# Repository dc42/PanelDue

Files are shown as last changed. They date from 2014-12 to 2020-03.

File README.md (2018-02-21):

PanelDue
========

This is the OLD source code for firmware versions 1.15x and earlier to run the PanelDue 3D printer user interface board. Source code for firmware versions 1.16 and later is in repository PanelDueFirmware, see https://github.com/dc42/PanelDueFirmware.

Build instructions: load file PanelDue.cppproj into Atmel Studio 7.0. For those wishing to build it under operating systems other than Windows, it should not be difficult to port it to Eclipse. The only libraries needed that are not included in this repository are the GCC toolchain libraries for the SAM3S.

Static analysis: parts of the firmware are formally verified using Escher C++ Verifier, hence the design-by-contract and other annotations. File ecv.h defines macros that make these annotations invisible to compilers.

Firmware upload instructions: see http://miscsolutions.wordpress.com/paneldue/

Licence and copyright
=====================

Copyright (c) 2015 Escher Technologies Limited. Licensed under the Creative Commons Attribution-NonCommercial 4.0 license. See https://creativecommons.org/licenses/by-nc/4.0/legalcode for a copy. Some parts of the firmware (c) Henning Karlsen. Some parts of the firmware (c) Atmel Inc.

Submitting pull requests
========================

I will only consider pull requests that meet the following standards:
- the code must compile warning-free, with very few exceptions
- existing design-by-contract annotations must be preserved, and contracts should be added for any new functions. Please asked for a copy of eCv++ Free Edition if you plan on making substantial changes.
- the coding style must be adhered to

Acknowledgements
================

Henning Karlsen - for the original versions of the TFT display driver, see http://www.henningkarlsen.com/electronics/
Atmel - for the Atmel Software Framework, which made programming the ATSAM3S a lot easier
MikroElectronika - for providing GLCD Font Creator, see http://www.mikroe.com/glcd-font-creator/
Andy (kwikius) - for writing a program to compress fonts generated by GLCD Font Creator

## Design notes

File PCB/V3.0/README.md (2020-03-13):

This is the schematic for the version 3.0 standalone PanelDue controller board. The PaneDue 5i with integrated display uses the same circuitry for the part that interfaces to the Duet, with the following changes:
1. A different 3.3V regulator chip is used
2. Connector X4 has a different pinout. Numbering the pins from the left (with the adjacent X4 legend), the pin connections are:
* Pin 1: PB6 (intended for rotary encoder push button)
* Pin 2: PA2 (intended for rotary encoder A pin)
* Pin 3: PA3 (intended for rotary encoder B pin)
* Pin 4: +3.3V
* Pin 5: Ground (rotary encoder common pin)

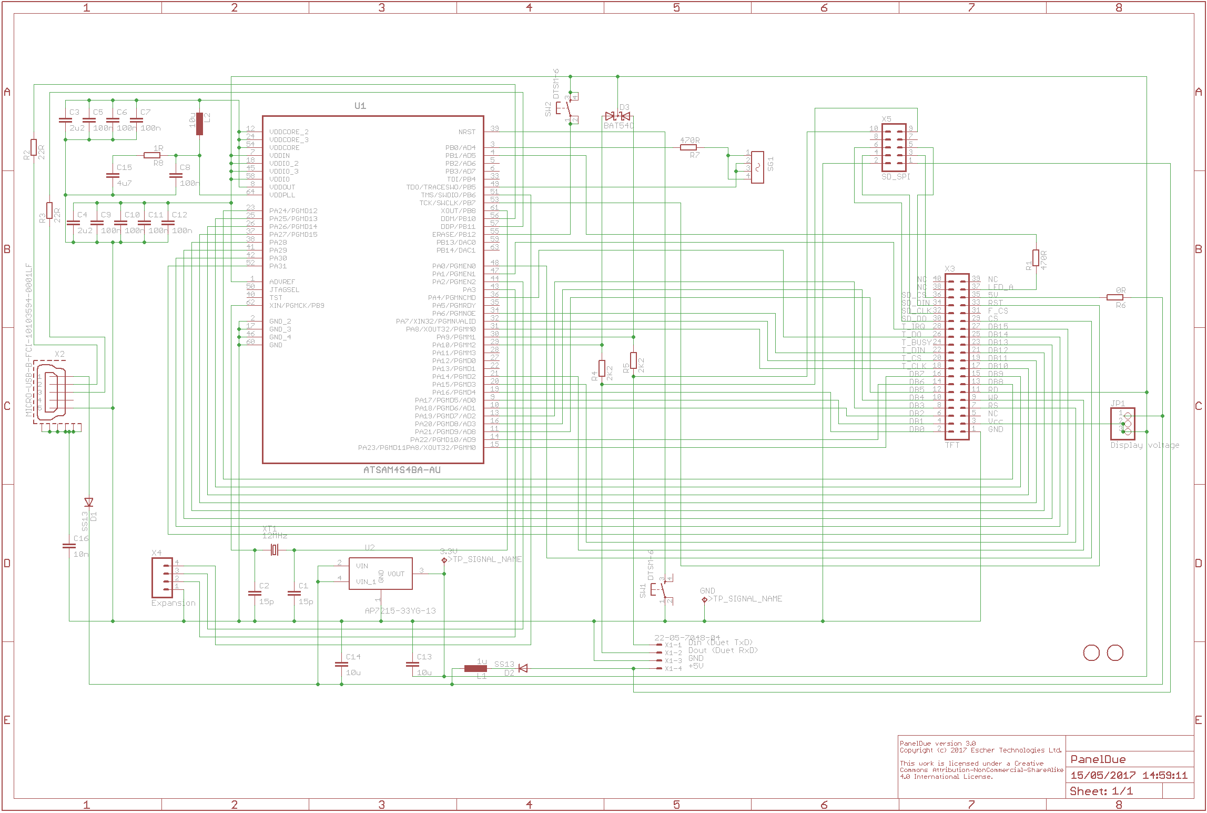
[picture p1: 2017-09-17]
PCB/V3.0/PaneDue-3.0-schematic.png

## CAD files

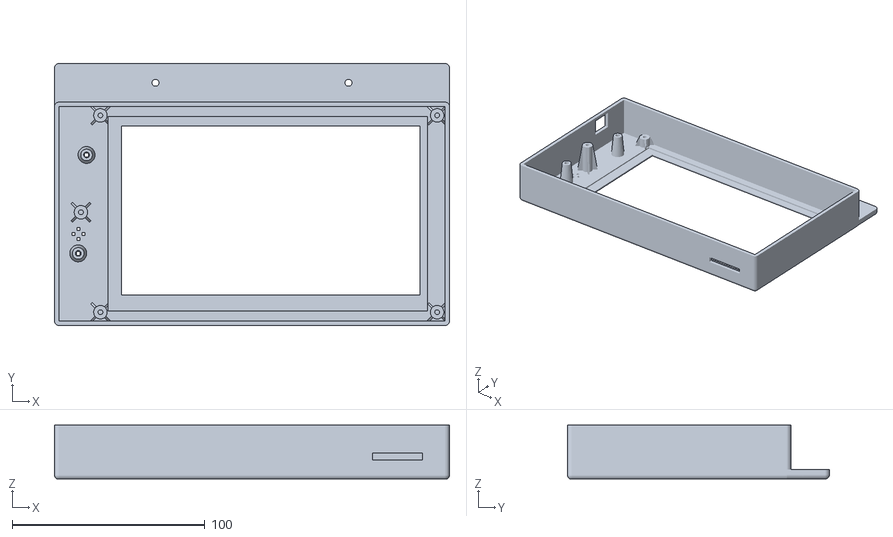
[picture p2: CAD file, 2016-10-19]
PrintedParts/PanelDueEnclosureWithLip-7.0-v2.0.stl
204.7 x 135.8 x 27.9

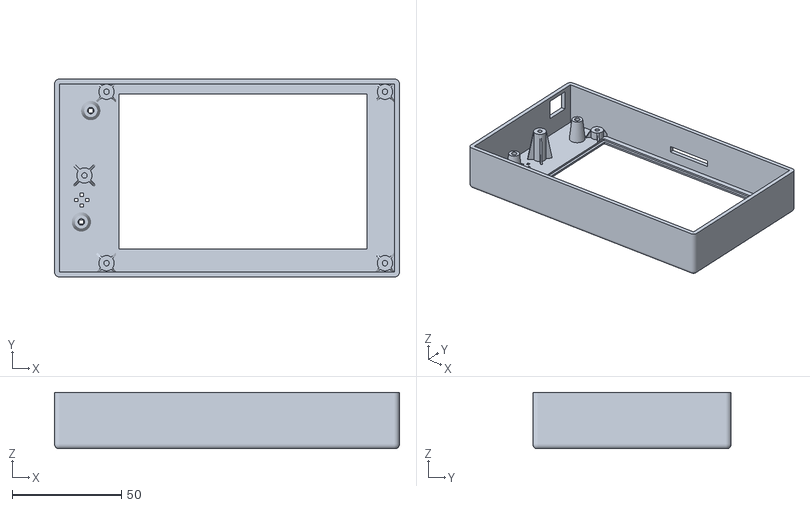
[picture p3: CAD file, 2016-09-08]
PrintedParts/PanelDueEnclosure-5.0-v2-sdslot.stl
158.0 x 90.8 x 25.8

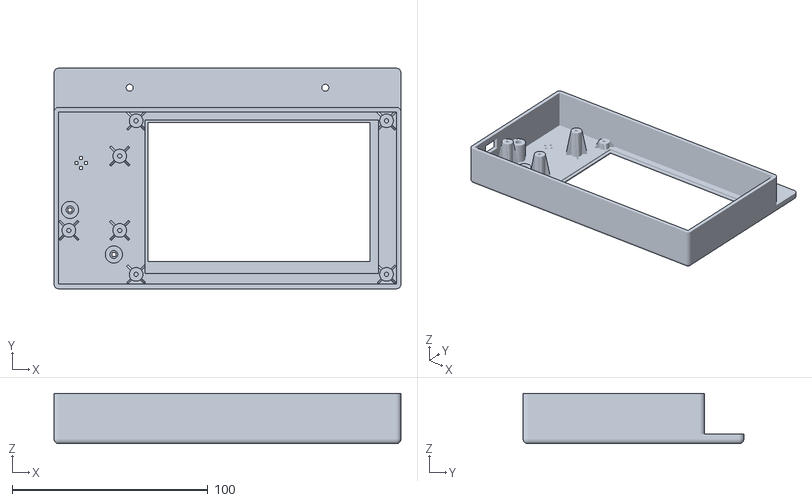
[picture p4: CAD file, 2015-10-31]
PrintedParts/PanelDueEnclosureWithLip-5.0-v1.1.stl
177.4 x 112.8 x 25.8

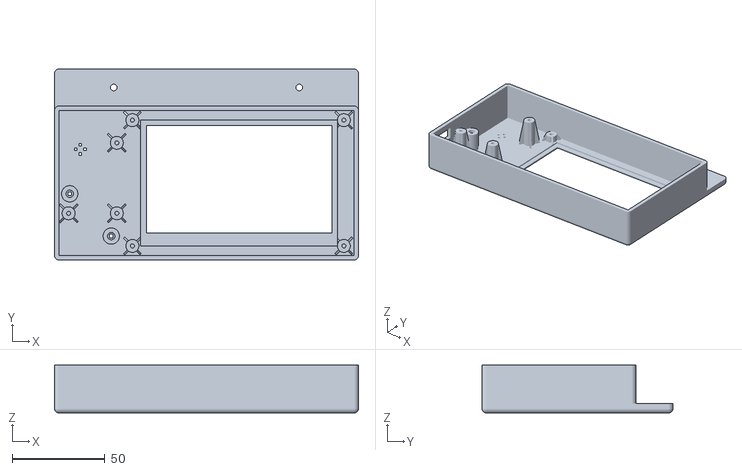
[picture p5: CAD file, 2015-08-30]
PrintedParts/PanelDueEnclosureWithLip-4.3-v1.1.stl
163.9 x 103.0 x 25.8

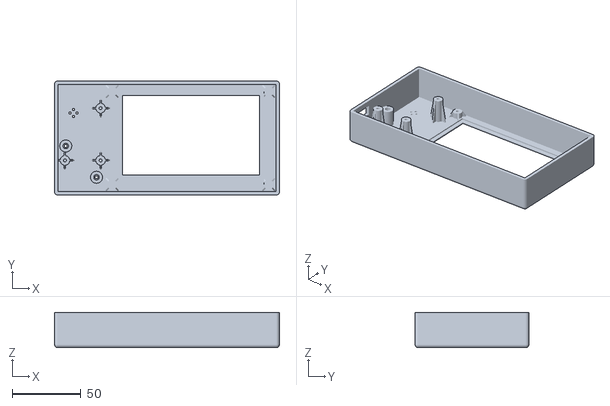
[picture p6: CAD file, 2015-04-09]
PrintedParts/PanelDueEnclosure-4.3-v1.1.stl
163.9 x 83.0 x 25.8

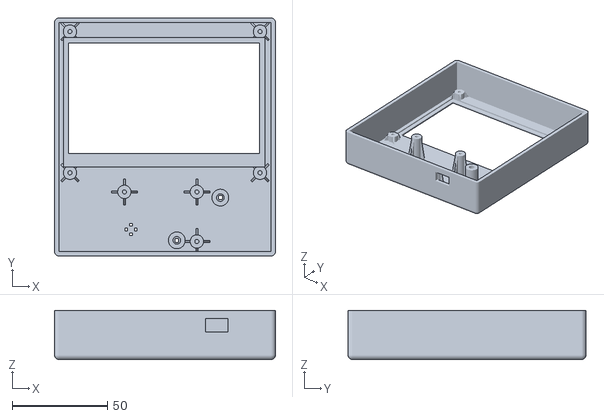
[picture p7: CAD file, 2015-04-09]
PrintedParts/PanelDueEnclosure-Itead-4.3.stl
115.8 x 124.7 x 25.8

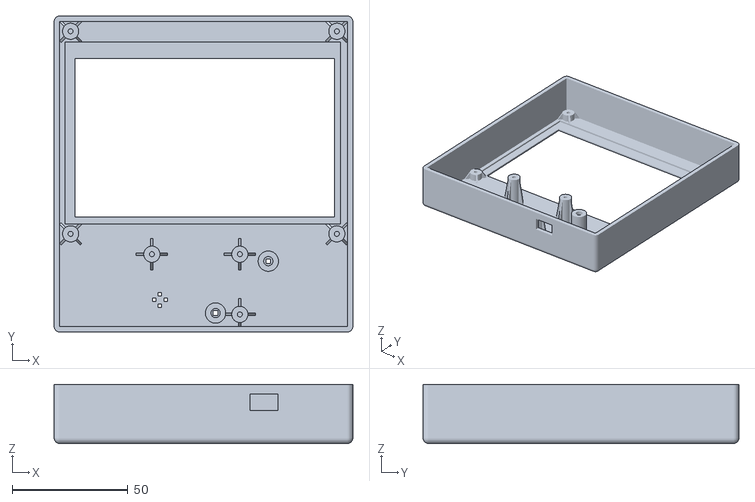
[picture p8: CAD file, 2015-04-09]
PrintedParts/PanelDueEnclosure-Itead-5.0.stl
129.0 x 136.5 x 25.5

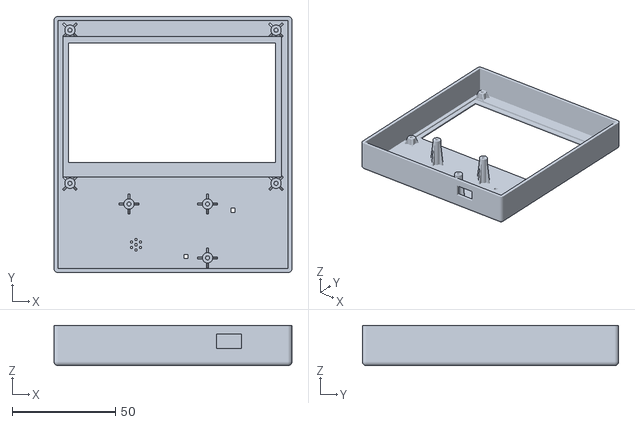
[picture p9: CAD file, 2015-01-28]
PrintedParts/LCD-box-itead-4.3.stl
115.0 x 123.9 x 19.5

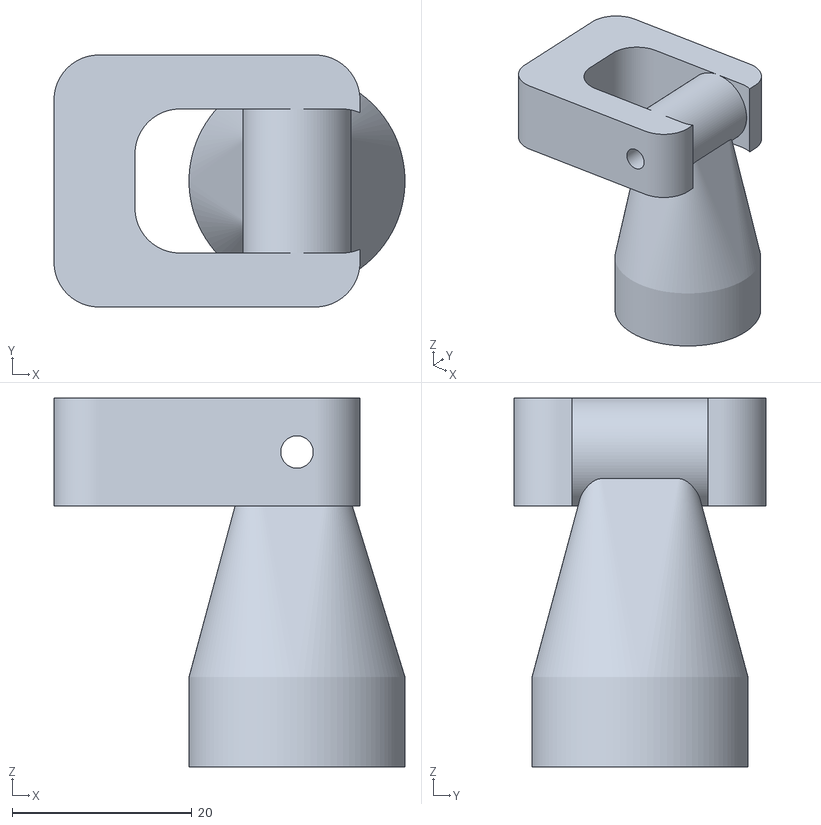
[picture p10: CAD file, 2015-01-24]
PrintedParts/appjaws-LCD-box-mount.stl
39.0 x 28.0 x 41.0

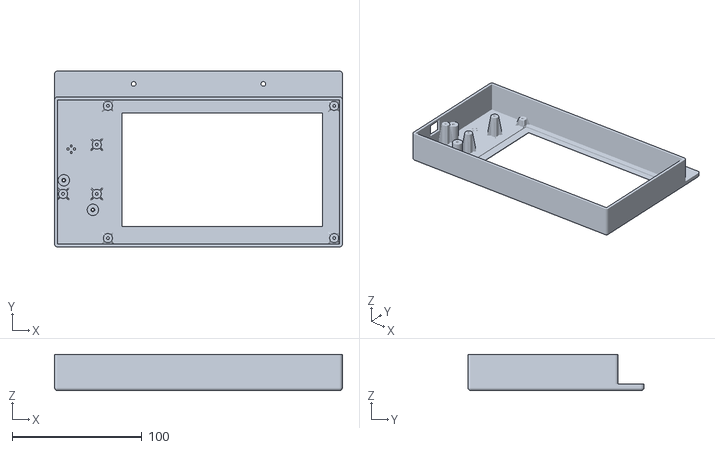
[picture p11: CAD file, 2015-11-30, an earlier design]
PrintedParts/PanelDueEnclosureWithLip-7.0-v1.1.stl
222.1 x 135.8 x 27.9

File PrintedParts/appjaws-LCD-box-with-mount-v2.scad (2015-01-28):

//This is based on the original by Dave (dmould) - thank you

// Print variables:
// 1) There is an overhang as the case starts printing in order to print the rounded front edges.
//    So long as the MMRadius (MMMRad) is small and the first layer height on the 3D printer is 
//    not too thin the printer should cope.  If however the overhang proves to be too much to
//    print set the "RelieveOverhang" variable non-zero up to 100 and the initial overhang will
//    be reduced proportionately to that number at the expense of a less rounded edge.
//	  (A value less than 30 is usually plenty sufficient).  Set to 100 to see the effect.
// 2) Set the "ShowPCB" variable to "true" to show the PCB shapes.
//    This is only in order to see how the PCBs will fit in the case, and should
//    not be used when generating an STL to print
// 3) If "Front" is set to true then parameters are interpreted as being viewed
//    from the front of the LCD, otherwise they are viewed from the back

// Set ONE of the following 3 variables true according to your display type
Itead43=false;
Itead50=true;
Other43=false;

Encoder=false;					// true if hole wanted for rotary encoder
Lid=false;						// set to false if lid not required
screw=true;						// set if screw lid
RelieveOverhang=0;				// see note 1 above

// Set up the main enclosure parameters
MWall=2;							// Main box MWall thickness
MBase=2;							// Main box MBase (front panel) thickness
MRad=MWall;						// MMRadius of box edges
Mclearance=2;						// clearance between board edge and inside of box
MBez=1;							// This is the thickness covering the non-visible
									// part of the LCD display (MBase thickness - recess)

USBclear=2;						// Clearance to leave all around USB connector
ResetHoleSide=2;					// Side of the square reset hole
BuzzerHoleSide=1;				// Side of the square buzzer holes

MountHeight=32;					// Height at which to put appjaws1's mount

//************ Leave what follows alone unless you want to change the design ****************

Left=Other43;						//true if controller board to left of display
Bottom=Itead43 || Itead50;		//true if controller board below the display
Right=false;
SmTol=0.1;						//small tolerence
LidSep=10;						// separation between box and lid
Tol=1;								//main tolerence
ShowPCB=false;
ShowLCD=false;
Front=true;


// LCD display module parameters
// NOTE - use any origin position you want and reference everything to that.
//        I have chosen the bottom left of the LCD screen as the origin, but
//        use anything and the code will sort it out.
//        co-ordinates are LCD display side down unless "Front" is "true".
LCDscrn= (Itead43) ? [0,105.6,0,67.8]
			: (Itead50) ? [0,119,0,78.6]
			: [0,106,0,67.8];	// The edges of the whole LCD screen area [Left,Right,Bottom,Top]

LCDview= (Itead43) ? [3,103,7,64.8]
			: (Itead50) ? [2.5,114.5,3,71.5]
			: [3,103,7,64.8];	// The edges of the visible region of the LCD screen (L,R,B,T)

LCDmounts= (Itead43) ?
			  [
				[2.7,-3.1],
				[102.3,-3.1],
				[2.7,70.9],
				[102.3,70.9],
			  ]
			: (Itead50) ?
			  [
				[1.5,-4.3],
				[116.5,-4.3],
				[1.5,83.2],
				[116.5,83.2],
			  ]
			: [						// Enter the relative coordinates [X,Y] of each mounting hole
				[-3.5,0],			// You may have as many mounting holes as you like
				[110.5,0],		// Each hole is defined separately for flexibility
				[-3.5,67.8],		// so that holes do not have to be on a rectangular pitch
				[110.5,67.8]		// ... add/remove as needed for modules with more/less mounting holes
			  ];					

LCDpcb = (Itead43) ? [-1,106,-6.1,73.6]
			: (Itead50) ? [-1,119.2,-7.8,85.4]
			: [-7,113,-3.2,71];	// The edges of the LCD PCB [Left,Right,Bottom,Top]
LCDheight= (Itead43) ? 5.3 : (Itead50) ? 5.0 : 5.3;	// Height of top surface of LCD above PCB (mount standoff height)
LCDmnthole=2;						// Hole to take self-tapping screw
LCDbossDia=5;						// Diameter of boss under each mounting hole
LCDbossD2=LCDbossDia*2;			// MBase diameter of boss supports
LCDbossFR=(LCDbossDia-LCDmnthole)/2; // Bottom fillet MMRadius of bosses
LCDsupW=1;						// Width of boss supports
LCDpin1=(Itead43) ? [28.2,-5.0] : (Itead50) ? [35.8,-5.0] : [108.5,10.0];

// Controller PCB module parameters
// The origin for these coordinates is pin 1 of the 40-pin connector, which is assumed to be 
// oriented with the long edge in the Y direction.
//        co-ordinates are from back of PCB (looking into back of case) unless "Front" is true.
PCB =[0,47.3,0,69.2];			// The edges of the controller PCB [Left,Right,Bottom,Top]
PCBmounts=[						// Enter the relative coordinates [X,Y] of each mounting hole
			[18.1, 16.0],			// You may have as many mounting holes as you like
			[44.1,16.0],			// Each hole is defined separately for flexibility
			[18.1, 54.0]
			 ];					
PCBshaft=[32.1,16.0];			// XY co-ordinates of rorary encoder shaft
PCBreset=[21.1,3.7];			// Coordinates of the reset button
PCBerase=[43.5,26.5];			// Coordinates of the erase button
PCBUSB=[PCB[1],5.6,1.2];		// Coordinates of the USB port inc. height from top surface of board
PCBpin1=[10.0,8.4];				// Coordinates of pin 1 of the 40-pin LCD connector
PCBbuzzer=[37.8,50.5];			// Coordinates of buzzer

PCBshaftDia=7;					// Diameter of hole for rotary encoder shaft
PCBheight=13;						// Height controller PCB above LCD standoff
PCBmnthole=2;						// Hole to take self-tapping screw
PCBbossDia=5;						// Diameter of boss under each mounting hole
PCBbossD2=PCBbossDia*2;			// MBase diameter of boss supports
PCBbossFR=(PCBbossDia-PCBmnthole)/2; // Bottom fillet MMRadius of bosses
PCBsupW=1;						// Width of boss supports

// Set the size of the enclosure
MLen= (Left) ? LCDpin1[0] - LCDpcb[0] + PCB[1] - PCBpin1[0] + 2*Mclearance
				: LCDpcb[1] - LCDpcb[0] + 2*Mclearance;		// Cavity length
MWid= (Bottom) ? LCDpcb[3] - LCDpin1[1] + PCB[1] - PCBpin1[0] + 2*Mclearance
				: LCDpcb[3] - LCDpcb[2] + 2*Mclearance;		// Cavity width
MHt=PCBheight+4.5;				// Cavity height

// Set the positions & orientation of LCD and PCB within the enclosure
// NOTE - these are offsets from center of enclosure to origin of LCD
LCDpos=[
			(Left) ? -(LCDpcb[0] + LCDpin1[0] - PCBpin1[0] + PCB[1])/2
					: -(LCDpcb[0] + LCDpcb[1])/2,
			(Bottom) ? -(LCDpcb[3] + LCDpin1[1] + PCBpin1[0] - PCB[1])/2
					: -(LCDpcb[2] + LCDpcb[3])/2
		];		// XY position of LCD visible screen center from case center.

PCBpos=[	LCDpos[0] + LCDpin1[0] - PCBpin1[(Bottom) ? 1 : 0],
			(Bottom) ? LCDpos[1] + LCDpin1[1] + PCBpin1[0] : LCDpos[1] + LCDpin1[1] - PCBpin1[1]
		];					// XY position of controller PCB origin from case center.
PCBrot= (Itead43 || Itead50) ? -90 : 0;	// Degrees to rotate controller PCB within enclosure

USBsize=[8,3];					// Length and height of USB connector on PCB

DuetConLen=10;
DuetConWid=6;
Lidmounts=[						// Enter the relative coordinates [X,Y] of each mounting hole
		[(MLen/2)-2,(MWid/2)-2],	// You may have as many mounting holes as you like
		[(MLen/2)-2,-(MWid/2)+2],	// Each hole is defined separately for flexibility
		[-(MLen/2)+2,-(MWid/2)+2],	// so that holes do not have to be on a rectangular pitch
		[-(MLen/2)+2,(MWid/2)-2]	//  add/remove as needed for modules with more/less mounting holes
			 ];						// ...
Lidstandoffheight=MHt;			// Height of top of LCD above PCB (mount standoff height)
Lidmnthole=2;					// Hole to take self-tapping screw
Lidmntclearhole=2.2;			// hole clearence for lid screws
LidbossDia=5;					// Diameter of boss under each mounting hole
LidbossD2=LidbossDia*2;		// MBase diameter of boss supports
LidbossFR=(LidbossDia-Lidmnthole)/2; // Bottom fillet MMRadius of bosses
LidsupW=1;						// Width of boss supports

overlap=0.1;
$fn=50;  // 50 is good for printing, reduce to render faster while experimenting with parameters


/////////////////////////////////////////////////////////////////////////////////////////////////////
/////////////////////////////////////////////////////////////////////////////////////////////////////
/////////////////////////////////////////////////////////////////////////////////////////////////////
/////////////////////////////////////////////////////////////////////////////////////////////////////

// CODE

mirror([Front ? 1:0,0,0])
{
	difference()
	{
		union()
		{
			RoundBox(MLen+2*MWall,MWid+2*MWall,MHt+MBase,MRad,MWall,MBase);
			translate([LCDpos[0],LCDpos[1],0]) LCDmnt();
			translate([PCBpos[0],PCBpos[1],0]) rotate([0,0,PCBrot]) PCBmnt();
		}
		translate([LCDpos[0],LCDpos[1],0]) LCDcutout();
		translate([PCBpos[0],PCBpos[1],0]) rotate([0,0,PCBrot]) USBcutout();
		if (Encoder) {
			translate([PCBpos[0],PCBpos[1],0]) rotate([0,0,PCBrot]) ShaftCutout();
		}
		translate([PCBpos[0],PCBpos[1],0]) rotate([0,0,PCBrot]) ResetCutout();
		translate([PCBpos[0],PCBpos[1],0]) rotate([0,0,PCBrot]) BuzzerHoles();
	}
	if (ShowLCD){
		translate([LCDpos[0],LCDpos[1],0]) LCDshape();
	}
	if (ShowPCB){
		translate([PCBpos[0],PCBpos[1],PCBheight+LCDheight+MBez]) rotate([0,0,PCBrot]) PCBshape();
	}
}
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

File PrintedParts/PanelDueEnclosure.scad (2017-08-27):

/* [Hidden] */
// This is based on the original by Dave (dmould) - thank you
// Updated 2016-01-03 to support version 1.1 PanelDue board and support Thingiverse customiser

// Print variables:
// 1) There is an overhang as the case starts printing in order to print the rounded front edges.
//    So long as the MMRadius (MMMRad) is small and the first layer height on the 3D printer is 
//    not too thin the printer should cope.  If however the overhang proves to be too much to
//    print set the "RelieveOverhang" variable non-zero up to 100 and the initial overhang will
//    be reduced proportionately to that number at the expense of a less rounded edge.
//	  (A value less than 30 is usually plenty sufficient).  Set to 100 to see the effect.
// 2) Set the "ShowPCB" variable to "true" to show the PCB shapes.
//    This is only in order to see how the PCBs will fit in the case, and should
//    not be used when generating an STL to print

/* [Size] */

// Which display panel do you have?
DisplayType=5;					// [1:Itead ITDB02-4.3,2:Itead ITDB02-5.0,3:Standard 4.3 inch,4:Standard 5 inch,5:7 inch]

// Which version PanelDue controller board do you have?
BoardVersion=2.0;				// [1.0,1.1,2.0]

/* [Options] */

// Do you want cutouts and mounting holes for a lid?
Lid=0;								// [0:No,1:Yes]

// Do you want a lip at the top for hanging the enclosure from a top horizontal extrusion?
Lip=1;								// [0:No,1:Yes]

// Do you want a slot for the SD card?
SDcard=1;							// [0:No,1:Yes]

// How much do you want to relieve the overhang of the rounded corners, to make it easier to print?
RelieveOverhang=10;				// [0:30]

/* [Hidden] */

/*
// Do you want a ball-and-socket mount?
Mount=0;							// [0:No,1:Yes]
*/

screw=true;						// set if screw lid
Encoder=false;					// true if hole wanted for rotary encoder (version 1.0 board only)

// Set ONE of the following 4 variables true according to your display type
Itead43=(DisplayType==1);
Itead50=(DisplayType==2);
Other43=(DisplayType==3);
Other50=(DisplayType==4);
Other70=(DisplayType==5);

// Set up the main enclosure parameters
MWall=2.4;						// Main box MWall thickness (multiple of extrusion width)
MBase=2;							// Main box MBase (front panel) thickness
MRad=MWall;						// MMRadius of box edges
Mclearance= (Lid) ? 5 : 1;		// clearance between board edge and inside of box
MBez=1;							// This is the thickness covering the non-visible
									// part of the LCD display (MBase thickness - recess)
MLip=20;							// width of lip
MLipThickness=5;

M3clear=3.6/2;

USBclear=2;						// Clearance to leave all around USB connector
ResetHoleSide=2;					// Side of the square reset hole
BuzzerHoleSide=1.5;				// Side of the square buzzer holes

ResetGuideInnerRadius=1.5;
ResetGuideLowerRadius=4.4;
ResetGuideUpperRadius=3.0;

MountHeight=32;					// Height at which to put appjaws1's mount

//************ Leave what follows alone unless you want to change the design ****************

Left=Other43 || Other50 || Other70;		//true if controller board to left of display
Bottom=Itead43 || Itead50;		//true if controller board below the display
Right=false;
SmTol=0.1;						//small tolerence
LidSep=10;						// separation between box and lid
Tol=1;								//main tolerence
ShowPCB=true;
ShowLCD=true;

// LCD display module parameters
// NOTE - use any origin position you want and reference everything to that.
//        I have chosen the bottom left of the LCD screen as the origin, but
//        use anything and the code will sort it out.
LCDscrn =   (Itead43) ? [0,105.6,0,67.8]
			: (Itead50) ? [0,119,0,78.6]
			: (Other43) ? [0,106,0,67.8]
			: (Other50) ? [0,119.5,0,78.5]	// The edges of the whole LCD screen area [Left,Right,Bottom,Top]
			:             [0,165.5,0,101];

LCDview =   (Itead43) ? [3,103,7,64.8]
			: (Itead50) ? [2.5,114.5,3,71.5]
			: (Other43) ? [3,103,7,64.8]
			: (Other50) ? [4.5,118,6,77]		// The edges of the visible region of the LCD screen (L,R,B,T)
			:             [4,158.5,8.5,96];

LCDmounts= (Itead43) ?
			  [
				[2.7,-3.1],
				[102.3,-3.1],
				[2.7,70.9],
				[102.3,70.9]
			  ]
			: (Itead50) ?
			  [
				[1.5,-4.3],
				[116.5,-4.3],
				[1.5,83.2],
				[116.5,83.2]
			  ]
			: (Other43) ? [		// Enter the relative coordinates [X,Y] of each mounting hole
				[-3.5,0],			// You may have as many mounting holes as you like
				[110.5,0],		// Each hole is defined separately for flexibility
				[-3.5,67.8],		// so that holes do not have to be on a rectangular pitch
				[110.5,67.8]		// ... add/remove as needed for modules with more/less mounting holes
			  ]
			: (Other50) ? [
				[-3.75,-0.5],
				[123.75,-0.5],
				[-3.75,78],
				[123.75,78]
			  ]
			:             [
			   [-5,-0.5],
			   [169.5,-0.5],
			   [-5,101.5],
			   [169.5,101.5]
			  ];					

LCDpcb =    (Itead43) ? [-1,106,-6.1,73.6]
			: (Itead50) ? [-1,119.2,-7.8,85.4]
			: (Other43) ? [-7,113,-3.2,71]
			: (Other50) ? [-7,126.5,-3.5,80.5]	// The edges of the LCD PCB [Left,Right,Bottom,Top]
			:             [-8,173,-4,105];

LCDheight = (Itead43) ? 5.3 
			: (Itead50) ? 5.0 
			: (Other43) ? 5.3 
			: (Other50) ? 5.3					// Height of top surface of LCD above PCB (mount standoff height)
			:             7.45;

LCDpin1=	  (Itead43) ? [28.2,-5.0] 
			: (Itead50) ? [35.8,-5.0]
			: (Other43) ? [110.8,10.0]
			: (Other50) ? [124.27,14.37]
			:             [170,26];

LCDmnthole=2.5;					// Hole to take self-tapping screw
LCDbossDia=7;						// Diameter of boss under each mounting hole
LCDbossD2=LCDbossDia*2;			// MBase diameter of boss supports
LCDbossFR=(LCDbossDia-LCDmnthole)/2; // Bottom fillet MMRadius of bosses
LCDsupW=1;						// Width of boss supports

// Controller PCB module parameters
// The 40-pin connector is assumed to be oriented with the long edge in the Y direction.
// Coordinates are from front of PCB.
PCB =[	0,
		(BoardVersion >= 2) ? 67.3 : 47.3,	// version 2 board is actually 65.3, the extra 2mm is to make wiring easier
		0,
		(BoardVersion > 1) ? 73.0 : 69.2
	  ];	// The edges of the controller PCB [Left,Right,Bottom,Top]
PCBmounts=(BoardVersion >= 2)
		 ? [						// Enter the relative coordinates [X,Y] of each mounting hole
			[56.0, 37.8]			// You may have as many mounting holes as you like
			]					
		 : (BoardVersion > 1)
		 ? [						// Enter the relative coordinates [X,Y] of each mounting hole
			[18.1, 16.0],			// You may have as many mounting holes as you like
			[18.1, 54.0]			// Each hole is defined separately for flexibility
			]					
		 : [						// Enter the relative coordinates [X,Y] of each mounting hole
			[18.1, 16.0],			// You may have as many mounting holes as you like
			[44.1, 16.0],			// Each hole is defined separately for flexibility
			[18.1, 54.0]
			];
//PCBshaft=[32.1,16.0];			// XY co-ordinates of rorary encoder shaft on V1.0 board
PCBreset= (BoardVersion >= 2)
			? [57.4,16.5]
			: [21.1,3.7];			// Coordinates of the reset button
PCBerase=	  (BoardVersion >= 2)
			? [53.1,67.5]
			: (BoardVersion > 1)
			? [37.5,22.5]
			: [43.5,26.5];		// Coordinates of the erase button
PCBUSB=	[PCB[1],
			(BoardVersion >= 2) ? 68.05 : 5.6,
			1.2];		// Coordinates of the USB port inc. height from top surface of board
PCBpin1= (BoardVersion >= 2)
			? [46.4,12.5]
			: [10.0,8.4];				// Coordinates of pin 1 of the 40-pin LCD connector
PCBbuzzer=  (BoardVersion >= 2)
			? [57.26,26.52]
			: (BoardVersion > 1)
			? [35.4,50.5]
			: [37.8,50.5];		// Coordinates of buzzer

PCBshaftDia=7;					// Diameter of hole for rotary encoder shaft
PCBheight=13;						// Height controller PCB above LCD standoff
PCBmnthole=2.5;					// Hole to take self-tapping screw
PCBbossDia=7;						// Diameter of boss under each mounting hole
PCBbossD2=PCBbossDia*2;			// MBase diameter of boss supports
PCBbossFR=(PCBbossDia-PCBmnthole)/2; // Bottom fillet MMRadius of bosses
PCBsupW=1;						// Width of boss supports

// Set the size of the enclosure
MLen= (Left) ? LCDpin1[0] - LCDpcb[0] + PCB[1] - PCBpin1[0] + 2*Mclearance
				: LCDpcb[1] - LCDpcb[0] + 2*Mclearance;		// Cavity length
MWid= (Bottom) ? LCDpcb[3] - LCDpin1[1] + PCB[1] - PCBpin1[0] + 2*Mclearance
				: LCDpcb[3] - LCDpcb[2] + 2*Mclearance;		// Cavity width
MHt=PCBheight+LCDheight+MBez+4.5;								// Cavity height
MActualLip = (Lip) ? MLip : 0;

// Set the positions & orientation of LCD and PCB within the enclosure
// NOTE - these are offsets from center of enclosure to origin of LCD
LCDpos=[
			(Left) ? -(LCDpcb[0] + LCDpin1[0] - PCBpin1[0] + PCB[1])/2
					: -(LCDpcb[0] + LCDpcb[1])/2,
			(Bottom) ? -(LCDpcb[3] + LCDpin1[1] + PCBpin1[0] - PCB[1])/2
					: -(LCDpcb[2] + LCDpcb[3])/2
		];		// XY position of LCD visible screen center from case center.

PCBpos=[	LCDpos[0] + LCDpin1[0] - PCBpin1[(Bottom) ? 1 : 0],
			(Bottom) ? LCDpos[1] + LCDpin1[1] + PCBpin1[0] : LCDpos[1] + LCDpin1[1] - PCBpin1[1]
		];					// XY position of controller PCB origin from case center.
PCBrot= (Itead43 || Itead50) ? -90 : 0;	// Degrees to rotate controller PCB within enclosure
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

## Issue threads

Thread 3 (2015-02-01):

[Feature Request] Add Fan Control to the Control Page

T3P3, 2015-02-01:
As the number of features to control increases it might be an idea to have these less frequently required controls (such as fan) relegated to a sub page.

dc42, 2018-02-21:
Firmware development has been moved to the PanelDueFirmware repository. Please create a new issue in that repository if this is still a requirement.

Closed 2018-02-21.

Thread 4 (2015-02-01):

[Discussion point] Axis positions should report commanded position.

T3P3, 2015-02-01:
When using the display to command long moves, for example Z200 to Z50 using the -5mm button. I tend to press the button more time than required because the head is still moving, and the reported position takes time to update.

If the number displayed was immediately the commanded position (possibly with a background change to indicate the difference) this would prevent going past the commanded position.

Thoughts?

dc42, 2018-02-21:
Firmware development has been moved to the PanelDueFirmware repository. Please create a new issue in that repository if this is still a requirement.

Closed 2018-02-21.

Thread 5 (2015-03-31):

Smoothie support

arthurwolf, 2015-03-31:
Hey !

Could you tell me what you think is needed for Smoothie to support this ?

Thanks :)

dc42, 2015-03-31:
Hi, and thanks for your interest. It would be good to get PanelDue
supported by other firmware, that would increase the volume and allow a
substantial reduction in the price.

To drive the PanelDue from other boards and firmware, this is what you
need to do:

1. Identify a spare serial port on the board, to which PanelDue can be
connected.

2.  Add firmware code to initialize that port, accept gcodes from it,
and send responses to those gcodes to it. PanelDue currently defaults to
57600 baud, but this is configurable and the default may be increased to
115200 baud in future. It uses 8 data bits, 1 stop bit, no parity bit.

3. Preferably, add the facility to ignore commands received from the
serial port that do not include a valid checksum, in order to increase
the immunity to noise. PanelDue always sends a line number (which is
currently always zero) and a checksum when it sends commands.

4. Implement support for the following gcodes, as documented at
http://reprap.org/wiki/G-code:

M20 S2
M36
M105 S2
M105 S3

It is not essential to return all the variables listed, but missing
variables may cause the functionality to be reduced.

Any characters with values outside the ASCII range 0 thru 127 (e.g.
accented character in filenames) are sent and received in UTF-8 format.
Currently, PanelDue supports code points 0 thru 255 only (i.e. Latin-1).
If Smoothieware uses the fatfs library to access the filing system on
the SD card, then fatfs already does the necessary UTF8 encoding and
decoding, provided you configure an appropriate code page in the fatfs
config file.

Please let me know if you need further information. The source code for
PanelDue firmware is at https://github.com/dc42/PanelDue.

Best regards

David Crocker, Escher Technologies Ltd.
http://www.eschertech.com
Tel. +44 (0)20 8144 3265 or +44 (0)7977 211486

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

arthurwolf, 2015-03-31:
Hey !

Thanks for answering so fast.

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

Have that.

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

Have that.

Defaults to 115200, but it's configurable in the config file.

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

We have checksums.

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

I have a problem here with the S2/S3 extensions.

M105 is "get extruder temperature". Firmwares already have a way to answer
to that that is very standard.
There is no clean way to add all the other information to the output that
would be coded in a clean fashion.
Using M105 for this complexifies things enourmously if the firmware is very
partitionned like Smoothie.

Why didn't you use another G-code like M408 or something ? That's what's
usually done for new functionality.
That would have been easier and even trivial to implement in other
firmwares then, and wouldn't interfere with existing functionality.

The cleanest way I see to implement this in Smoothie ( which is not really
clean at all, but less wrong than others ) is to implement a "PanelDue
compatibility" module that answers if S2/S3 is present, and teach the other
modules to ignore M20/M105 if S2/S3 is present.
But I don't like that at all ...

Are those S-extensions set in stone ? You are the only one to implement
them as far as I can see.
Could you use new G-codes for this ? ( and still keep your firmware
answering to the S-extension for backwards compatibility ) ?
Would that be very difficult ?

I like the idea of answering JSON, it's going to help a lot for the web
interface :) But the syntax you have now to ask for it is problematic.

Tell me what you think.

Cheers !!

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

--
Courage et bonne humeur.

dc42, 2015-03-31:
The reasons I chose M105 S2 are:

1. There was already a proposal to use M105 S1 to send back additional
status information, see the wiki.

2. Some firmwares already treat M105 specially, in that they allow M105
requests to be processed even while other gcode commands are stalled
waiting for something to happen, e.g. waiting for temperatures to
stabilise. This same functionality is useful for the status information
requests made by PanelDue.

I am not against moving the status poll to another M code, however there
should still be an S parameter to indicate the format requested.  The
JSON response returned by M105 S2 is almost identical to the response
returned by the web interface until about a month ago. However, the web
interface has moved on since then, and the response for the new web
interface is a much more complex JSON structure. It is likely that I
will eventually change PanelDue firmware to request this more complex
structure, in order to increase functionality. So the M408 (or whatever)
code should take an S parameter to indicate the version of the response
required, just as the web interfaces does. See
http://reprap.org/wiki/Proposed_RepRap_Duet_Status_Responses for the
new-format status responses.

btw if you are thinking of doing work on the web interface, then I
strongly suggest you look at
https://github.com/zombiepantslol/DuetWebControl to avoid re-inventing
the wheel.

Regards

David Crocker, Escher Technologies Ltd.
http://www.eschertech.com
Tel. +44 (0)20 8144 3265 or +44 (0)7977 211486

arthurwolf, 2015-04-01:
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

People tend to just pick whatever pops into their mind when adding bits to
the communication protocols like this :)
Which is why we have several G-codes with dual meaning, or differing
outputs ...
I really think "return general information about the machine as JSON" is
different enough from "return temperatures as short string" to warrant it's
own M-code.

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

Yeah it'd make sense that M408 ( or whatever ) behave the same way.

>
> I am not against moving the status poll to another M code,

Yay !

> however there
> should still be an S parameter to indicate the format requested.

Yes that's definitely a good idea.

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

There should also be a M-code to ask what formats are supported by a given
board ...

I think the proposed Reprap Duet status responses should be renamed
proposed Reprap status responses :)
Then we get those implemented into Smoothie, and we have a standard :)

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

We already have something much more complex in the works ( it's called
Mousse, and it's built with modules like Smoothie ), with lots of crazy
features planned
But it'd be nice to get the communication protocols as close as possible
together, so that Mousse could talk to a Duet, and DuetWebControl could
talk to a Smoothie ...

https://github.com/arthurwolf/Mousse
https://www.youtube.com/watch?v=NKwcuq5O-mc

Cheers.

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

--
Courage et bonne humeur.

arthurwolf, 2015-04-05:
Hey !

Got my panel yesterady.
Tried it just now. The panel itself works, but when connected to the
Smoothieboard, it always says "connecting" but never actually connects.
Is this something to be expected from not having the M105 S implementation ?
Or is the panel waiting for some specific "welcome message" from the
Smoothieboard ? ( that's a problem we often have with GRBL-centric host
applications that expect the board to say "grbl" when it boots )

Cheers !

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

--
Courage et bonne humeur.

dc42, 2015-04-05:
Hi Arthur,

The PanelDue is waiting for the response to the M105 S2 command. I can
do you a variant that uses M408 instead (I think that's what you
suggested) if it helps.

Best regards

David Crocker, Escher Technologies Ltd.
http://www.eschertech.com
Tel. +44 (0)20 8144 3265 or +44 (0)7977 211486

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

chrisbrent, 2016-03-01:
Hi David,
 My PanelDue arrived (well it's at DHL waiting for me to pick it up :) and I've been working on the M408 code for Smoothie. Can you do me a variant that asks for that instead of M105 S2?
Chris
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
arthurwolf, 2016-11-08:
M104 is standard Reprap Gcode, G10 as retract too, so breaking that is out
of question.
http://reprap.org/wiki/G-code#G10:_Tool_Offset

I think 1 is the only reasonable solution.

David : Why are you doing that ?

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

--
Courage et bonne humeur.

chrisbrent, 2016-11-09:
Good idea on the new pull request. The old one is a mess anyway. I update to this when I finally get time to come back to it. The panel might be a bit nicer to use if it could be configured by the M408, i.e if there is no standby temp pass back from the firmware don't show that. It feels a very proprietary right now.

dc42, 2016-11-09:
Hi all,

First a little bit of history. G10 is the standard CNC NIST code for setting tool coordinate offsets. See e.g. http://ws680.nist.gov/publication/get_pdf.cfm?pub_id=823374. Adrian Bowyer implemented it as such in RepRapPro's fork of Marlin. So it was really dumb of other Marlin devs to hijack it as firmware retraction. As you guys are big in controlling CNC machines, I am a little surprised that you don't support setting tool coordinate offsets using G10 already.

Adrian Bowyer subsequently extended G10 to set tool temperatures too. The M104 command (see http://reprap.org/wiki/G-code#M104:_Set_Extruder_Temperature) is not really adequate for printers with multiple heads because there is no documented way of how to handle multiple heaters, whether on different tools or belonging to a single tool. Likewise M104 does not provided any way of setting standby temperatures, which are highly beneficial for ooze suppression in multi-head printers. So for firmware supporting flexible configuration of tools as RRF does, G10 is the only sensible command to use for setting temperatures.

Regarding PanelDue/Smoothieware compatibility, I can see a few options:

1. Use a separate PanelDue firmware build for Smoothieware. Not a good option for users.

2. Add a firmware configuration option in the Setup page to specify which firmware is being used. Better than (1) but still not good.

3. Change Smoothieware to handle G10 the way RRF does, i.e. treat it as a retraction command if there is no P parameter, and a command to set tool offsets and/or temperatures if there is.

4. We add a field in the M408 extended status response to identify the host firmware. When Smoothieware is detected, the behaviour is changed to send M104 instead of G10. I presume you would also want the standby temperature fields hidden if you don't support them. There are a few decisions you will need to make, e.g. if the user tries to change the temperature on a head other than the one selected, what should be the response? Also it might be wise to change Smoothieware to ignore a G10 command with a P parameter, in case the user tries to change temperatures before the firmware type has been established.

I suspect that #4 would work best for you.

AHHams, 2016-11-09:
@dc42: your 4. is my 3.  I guess it would not be too difficult for me to work on a pull request for PanuelDue to deal with this, since you already have the GUI react to geometry.

Does it make sense to start adopting the new M408 output as shown [here](http://reprap.org/wiki/RepRap_Firmware_Status_responses) on both ends (as it includes firmwareName in the spec). Or first just add "firmwareName=Smoothieware" to the current output and get that to work first?

arthurwolf, 2016-11-09:
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

Actually we do, that's a big part of the problem.

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

Sure there, is, the T command ... no ?

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

--
Courage et bonne humeur.

dc42, 2016-11-09:
Currently the JSON parser in PanelDue firmware does not support parsing
nested objects. So for now I suggest adding "firmwareName=Smoothieware"
to the existing extended status response.

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

dc42, 2016-11-09:
Hi Arthur,

The T command is for selecting a tool. I don't see how it can be used
for setting temperatures, let alone for setting the temperatures of
multiple heaters on a tool.

Cheers David

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

arthurwolf, 2016-11-09:
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

It's not.
M104 is used for setting the temperature for the heater associated to a
specific tool.
This is standard Reprap gcode as far as I know. It's what the slicers do,
it's what we do, I believe other firmwares do this too.
Nobody asked us to have several heaters associated with a single tool yet,
but I don't see why that couldn't be done with an extension to M104 ...

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

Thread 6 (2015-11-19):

Button related UX suggestions

BrianGilbert, 2015-11-19:
After a discussion about this you and I came up with the following solutions:

-On settings screen allow clicking of other settings buttons when a modal is displayed
-Make bottom tabs always clickable

dc42, 2016-04-14:
Fixed in version 1.13.

Closed 2016-04-14.

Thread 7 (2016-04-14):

Inconsistent layer height display.

y00rek, 2016-04-14:
I just noticed a slight inconsistency with layer height display. I DWC the layer height is displayed correctly as 0.25. PanelDue in print confirmation popup (the one that gets displayed when a file from SD card is selected for printing) displays it as 0.3. There must be some rounding going on here. It does not affect anything but just for the sake of being pedantic....

dc42, 2016-04-14:
Thanks for your report. The layer height is currently displayed to only 1 decimal place. I will increase it to 2 in the next release.

dc42, 2018-02-21:
Firmware development has been moved to the PanelDueFirmware repository. Please create a new issue in that repository if this is still a problem.

Closed 2018-02-21.

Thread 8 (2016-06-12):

Feature Request: innocuous display of the Duet's IP address

dcnewman, 2016-06-12:
Nice to be able to power up the printer and see right away on the Panel Due the IP address assigned to the underlying Duet or Duet WiFi.  Yes, it can be found by going to the console and manually entering a command, but might be nice to have it just there in small type somewhere on the main screen.

dc42, 2018-02-21:
Firmware development has been moved to the PanelDueFirmware repository. Please create a new issue in that repository if this is still a requirement.

Closed 2018-02-21.

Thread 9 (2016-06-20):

Incorrect layer fan percentage display

y00rek, 2016-06-20:
The layer fan speed is not shown correctly. DWC shows it as 100% whereas PanelDue shows it as 1%
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

dc42, 2018-02-21:
Firmware development has been moved to the PanelDueFirmware repository. Please create a new issue in that repository if this is still a problem.

Closed 2018-02-21.

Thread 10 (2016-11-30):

Support Small Size LCD

Laiwxn, 2016-11-30:
Now，the firmware does not support the Small Size LCD，such as ILI9327 controller.But I wanna a small LCD.A large LCD for a small 3D printer is strange，thanks！

dc42, 2016-11-30:
A smaller LCD would provide much less functionality, for example less information displayed and no touch keyboard to allow you to enter gcode commands. Even the 3.2" screen that I started out using proved too small, that's why we chose 4.3" as the minimum size supported. But the firmware is open source and the display driver it uses includes support for the IL9327, so feel free to adapt it to a smaller screen if you want.

Laiwxn, 2016-11-30:
You mean that,the later codes also support ILI9327?The latest codes contains the driver for ILI9327 or I must copy the driver from the old codes to new code and Rebuild it?

dc42, 2016-12-07:
I mean that the TFT screen driver in the current source code supports the ILI9327 and a number of other TFT panel driver chips. You define which chip you want to use in file src/hardware/memorysaver.h.

Laiwxn, 2016-12-07:
Got it，thanks!

Closed 2017-05-09.

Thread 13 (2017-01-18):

PanelDue does not recognize SD card with RADDS

AbuShaqra, 2017-01-18:
Hello, I've finally got the PanelDue to work with my RADDS board using repetier firmware.

but I am still facing a problem that the PanelDue shows that there is no SD card in both case when I use the RADDS onboard slot or the slot on the back of the TFT.

 I've got the 10p ribbon cable connected to the external SD pins and I checked all my wiring, no luck so far. any help would be highly appreciated

dc42, 2017-01-18:
Hi,

1. Repetier does not yet fully support PanelDue. The Repetier devs have been working on this, also I am going to make some changes to PanelDue to make it easier for them. If you can't list the contents of the builtin card on PanelDue, then I guess they haven't implemented the M20 S2 command yet, which is what PanelDue needs for the file list to work.

2. The RADDS SD card pinout is different from the pinout used by Duet WiFi and other electronics, so a straight through 10-pin cable won't work with RADDS.

3. It's also possible to run RepRapFirmware on RADDS, with full PanelDue support.

AbuShaqra, 2017-01-18:
Thank you for the quick reply David.

So can I say that if I get the wiring right and add support for the M20 S2 command I can get it to work?

I will give the RepRap Firmware  a try, it's just that I prefer using the repetier because I have previous experience with it.

dc42, 2017-01-18:
There is one complication. Currently, RRF looks in folder /gcodes on the SD card for gcode files on the first SD card. It's occurred to me that perhaps Repetier does already support M20 S2, but you have no /gcodes folder so you don't see any files. One of the changes I am planning is that when the host includes "firmwareName":"Repetier" in the extended status response (see http://reprap.org/wiki/G-code#M408:_Report_JSON-style_response), it will look in the root folder instead.

AbuShaqra, 2017-01-18:
All clear, can you give me a tip on which fork of RepRapFirmware I can use the best for RADDS board.

And if there is a complete documentation for how to flash and configure it. thank you

AbuShaqra, 2017-01-18:
Alright, I tried flashing the "RepRapFirmware-RADDS-1.17c.bin" release and first I specified the port as COM3 where my board appeared in the device manager, I got this message; No device found on COM3.

this is the command I used: bossac.exe --port=COM3 -e -w -v -b "C:\Users\Abu Shaqra\Downloads\RepRapFirmware-RADDS-1.17c.bin"

I then used this command: bossac.exe -e -w -v -b "C:\Users\Abu Shaqra\Downloads\RepRapFirmware-RADDS-1.17c.bin"

and got this error:  Auto scan for device failed
                               Try specifying a serial port with the '-p' option

dc42, 2017-01-18:
Press the Erase button on the Due. Then look in Device manager for which
port is the "Bossa port". Then run bossac using that port.

David Crocker, Escher Technologies Ltd.
http://www.eschertech.com
Tel. +44 (0)20 8144 3265 or +44 (0)7977 211486

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

AbuShaqra, 2017-01-19:
thank you

dc42, 2018-02-21:
Firmware development has been moved to the PanelDueFirmware repository. Please create a new issue in that repository if this is still a requirement.

Closed 2018-02-21.

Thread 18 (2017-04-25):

My list of PanelDue Requests

Eddiiie, 2017-04-25:
Unable to change temperature of heater1 when any tool besides 1 is selected, example touch tool 2 and set the temp, it will not work.  I have mixing extruder (diamond hotend) and have only 1 heater.   Works fine from webgui.
Add Z height to Print Status screen
Add Layer number to Print Status screen
Show which extruder/tool is active, or change the color so it is visible
Change font on exturder/tool buttons to make text readable
Display IP address somewhere, I forget it from time to time.
More color choices
Emergency Stop button

dc42, 2017-04-25:
Please log new issues in the new repository PanelDueFirmware, not this one.

Closed 2017-04-25.

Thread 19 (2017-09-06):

Adjusting Tool Flow Rate is Not Consistent With the Tool that the Change was Made to

bmalcheski, 2017-09-06:
This is best described with pictures which I have uploaded.

In "Panel 1" I was attempting to adjust the flowrate of Tool 3 to 99%. But it appears that either the value is just displayed in the wrong spot or that the change is applied to the wrong tool.

I then tried to change Tool 3 to 100% and get the result in "Panel 2." Again, the adjustment being applied to the wrong tool or the new value displayed in the wrong position.

I then adjusted Tool 1 to 100% and got the result in "Panel 3." I noticed this bug while in the middle of a large print so I did not want to do too much messing around but could do some more trouble shooting if necessary.

Panel 1
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

Panel 2
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

Panel 3
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

dc42, 2018-02-21:
This is believed fixed in the latest beta from the PanelDueFirmware repository. If you don't think it is fixed in that beta, please create a new issue in that repository.

Closed 2018-02-21.

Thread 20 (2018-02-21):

PanelDue doesn't show folders beyond first page ...

dotorg, 2018-02-21:
I'm having an issue that has made the PanelDue pretty much unusable for starting prints. The file listing seems to only support showing folder/directories on the first page. So anything more than eight, and there's no way to access them.

Strangely, too, I can't tell how its determining which eight to show. Its not the first or last alphabetically, and it doesn't seem to be date related, but it *is* consistent.

dc42, 2018-02-21:
Works fine for me, using the scroll buttons. Please check that your Duet and PanelDueFirmware versions are up to date, also check that the files are displayed correctly in DWC.

dotorg, 2018-02-21:
Both up to date, and it doesn't work for me. Files are displayed fine in the web console. Folders are only displayed on the first page. Obviously I'd used the scroll buttons, otherwise I wouldn't know they don't show up on any of the other pages.

Seems... bizarre... to just blindly close a bug that a paying customer reports just because you don't see it. "Well, we'll just ship your computer, then" is what I'd sarcastically say to any of the engineers in my organization who said that.  Should I just keep posting a new bug report until you accept there's something not working, or do you just not care something isn't?  If the latter is the case, I'll just fork and fix the bug myself.

PanelDue 1.17
All the Duet firmwares are 1.20, although the problem existed prior to that. I didn't have that many folders prior to the upgrade to 1.17 on the PanelDue, so I can't speak to if it was a problem on prior versions.

FWIW, looking at the code, I suspect the issue is not specifically directories not going beyond the first page, but the 2048 byte limit to the file list at FileManager.cpp:25, and its just a coincidence that eight directories happen to be in the file list prior to being truncated. The additional missing files aren't as obvious because I almost always work in subdirectories.

I'll just rebuild it with a bigger vector, but if its really behaving as intended, it may be worth documenting that there's  2kb limit to the total length of all the filenames shown in a directory. I'd bet people are running into it and not realizing it.

dc42, 2018-02-21:
I closed this report because it is in the wrong repository.

dotorg, 2018-02-21:
Should I repost it in the other one, then, with more specifics about the
issue?

I hope you understand how closing it without saying that, and a blanket
statement that there's no problem is ... off putting.

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

dc42, 2018-02-21:
Yes please.

Closed 2018-02-21.

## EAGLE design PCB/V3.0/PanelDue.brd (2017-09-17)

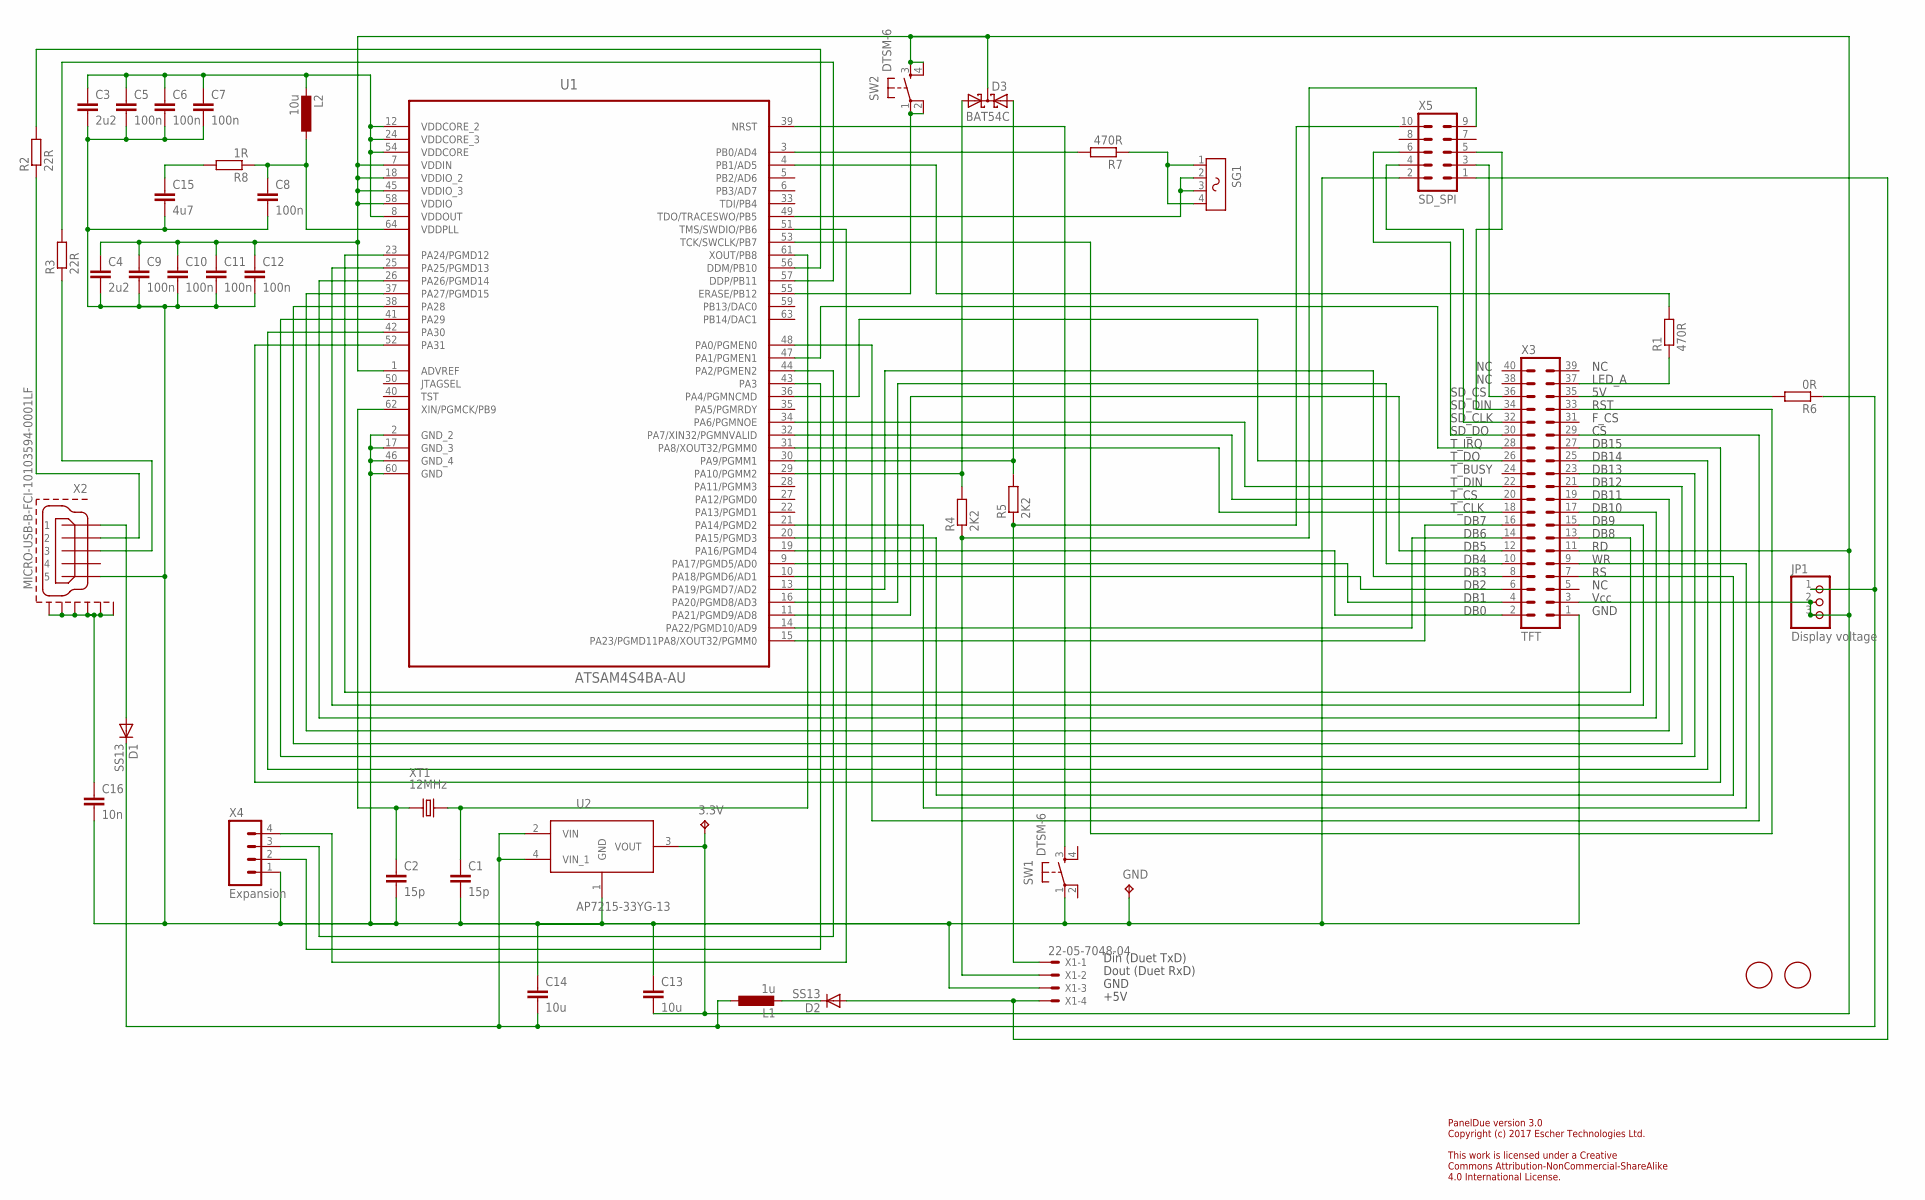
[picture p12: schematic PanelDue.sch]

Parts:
3.3V: TPPAD1-10; P1-10
C1, C2: 15p; C0603
C3, C4: 2u2; C0603
C5, C6, C7, C8, C9, C10, C11, C12: 100n; C0603
C13, C14: 10u; C0805
C15: 4u7; C0603
C16: 10n; C0603
D1, D2: SS13; DO214AC
D3: BAT54C; SOT23
GND: TPPAD1-10; P1-10
JP1: Display voltage; 1X03
L1: 1u; L2012C
L2: 10u; L2012C
R1, R7: 470R; R0603
R2, R3: 22R; R0603
R4, R5: 2K2; R0603
R6: 0R; R0603
R8: 1R; R0603
SG1: F/QMX2; F?QMX2
SW1, SW2: DTSM-6
U1: ATSAM4S4BA-AU; QFP50P1200X1200X160-64N
U2: AP7215-33YG-13; SOT150P400X160-4N
U$1, U$2: FIDUCIAL; FIDUCIAL_1MM
X1: 22-05-7048-04; 7395-04
X2: MICRO-USB-B-FCI-10103594-0001LF; 10103594-0001LF
X3: TFT; MA20-2
X4: Expansion; 1X04
X5: SD_SPI; ML10L
XT1: 12MHz; CRYSTAL-SMD-2PIN-5X3.2

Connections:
GND: C1.2, C2.2, C3.2, C4.2, C5.2, C6.2, C7.2, C8.2, C9.2, C10.2, C11.2, C12.2, C13.1, C14.1, C15.2, C16.2, GND.TP, SW1.1, U1.2 (GND_2), U1.17 (GND_3), U1.46 (GND_4), U1.60 (GND), U2.1 (GND), X1.3, X2.5, X3.1, X4.1, X5.2
unnamed: U1.19 (PA16/PGMD4), X3.2
unnamed: U1.31 (PA8/XOUT32/PGMM0), X3.18
unnamed: U1.9 (PA17/PGMD5/AD0), X3.4
unnamed: U1.10 (PA18/PGMD6/AD1), X3.6
unnamed: U1.16 (PA20/PGMD8/AD3), X3.10
unnamed: U1.14 (PA22/PGMD10/AD9), X3.14
unnamed: U1.11 (PA21/PGMD9/AD8), X3.12
unnamed: U1.15 (PA23/PGMD11PA8/XOUT32/PGMM0), X3.16
unnamed: U1.23 (PA24/PGMD12), X3.13
unnamed: U1.13 (PA19/PGMD7/AD2), X3.8
unnamed: U1.25 (PA25/PGMD13), X3.15
unnamed: U1.26 (PA26/PGMD14), X3.17
unnamed: U1.37 (PA27/PGMD15), X3.19
unnamed: U1.38 (PA28), X3.21
unnamed: U1.41 (PA29), X3.23
unnamed: U1.42 (PA30), X3.25
unnamed: U1.52 (PA31), X3.27
unnamed: R2.2, U1.56 (DDM/PB10)
unnamed: U1.34 (PA6/PGMNOE), X3.22
unnamed: U1.36 (PA4/PGMNCMD), X3.26
unnamed: C1.1, U1.61 (XOUT/PB8), XT1.P$2 (2)
unnamed: C2.1, U1.62 (XIN/PGMCK/PB9), XT1.P$1 (1)
unnamed: SW2.1, SW2.2, U1.55 (ERASE/PB12)
unnamed: C8.1, L2.1, R8.1, U1.64 (VDDPLL)
unnamed: SW1.3, U1.39 (NRST)
unnamed: D3.2 (A2), R5.2, U1.30 (PA9/PGMM1)
unnamed: D3.1 (A1), R4.2, U1.29 (PA10/PGMM2)
unnamed: R3.2, U1.57 (DDP/PB11)
unnamed: R4.1, X1.2, X5.9
unnamed: R5.1, X1.1, X5.10
unnamed: D1.A, X2.1
unnamed: R2.1, X2.2
unnamed: R7.2, U1.3 (PB0/AD4)
unnamed: R3.1, X2.3
unnamed: U1.32 (PA7/XIN32/PGMNVALID), X3.20
unnamed: U1.47 (PA1/PGMEN1), X3.28
unnamed: R1.1, X3.37
unnamed: X3.36, X5.3
unnamed: R7.1, SG1.1, SG1.4
unnamed: U1.43 (PA3), X4.2
unnamed: U1.44 (PA2/PGMEN2), X4.3
unnamed: U1.53 (TCK/SWCLK/PB7), X3.33
unnamed: U1.48 (PA0/PGMEN0), X3.29
unnamed: U1.21 (PA14/PGMD2), X3.9
unnamed: D2.C, L1.2
unnamed: C16.1, X2.GND1, X2.GND2, X2.GND3, X2.GND4, X2.GND5, X2.GND6
unnamed: U1.20 (PA15/PGMD3), X3.7
unnamed: C15.1, R8.2
unnamed: D2.A, X1.4, X5.1
unnamed: X3.34, X5.5
unnamed: R1.2, U1.4 (PB1/AD5)
unnamed: U1.51 (TMS/SWDIO/PB6), X4.4
unnamed: SG1.2, SG1.3, U1.49 (TDO/TRACESWO/PB5)
unnamed: C3.1, C5.1, C6.1, C7.1, L2.2, U1.8 (VDDOUT), U1.12 (VDDCORE_2), U1.24 (VDDCORE_3), U1.54 (VDDCORE)
unnamed: X3.32, X5.4
unnamed: X3.30, X5.6
unnamed: R6.2, X3.35
VCC: 3.3V.TP, C4.1, C9.1, C10.1, C11.1, C12.1, C13.2, D3.3 (CC), JP1.2, JP1.3, SW2.3, SW2.4, U1.1 (ADVREF), U1.7 (VDDIN), U1.18 (VDDIO_2), U1.45 (VDDIO_3), U1.58 (VDDIO), U2.3 (VOUT), X3.3, X3.11
VCC5: C14.2, D1.C, JP1.1, L1.1, R6.1, U2.2 (VIN), U2.4 (VIN_1)

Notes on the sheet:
T_BUSY
SD_CS
SD_DIN
SD_CLK
SD_DO
T_IRQ
GND
Vcc
DB0
DB1
DB2
DB3
DB4
DB5
DB6
DB7
T_CLK
T_CS
T_DIN
T_DO
DB8
DB9
DB10
DB11
DB12
DB13
DB14
DB15
F_CS
RST
LED_A
+5V
Dout (Duet RxD)
Din (Duet TxD)
PanelDue version 3.0 Copyright (c) 2017 Escher Technologies Ltd. This work is licensed under a Creative Commons Attribution-NonCommercial-ShareAlike 4.0 International License.

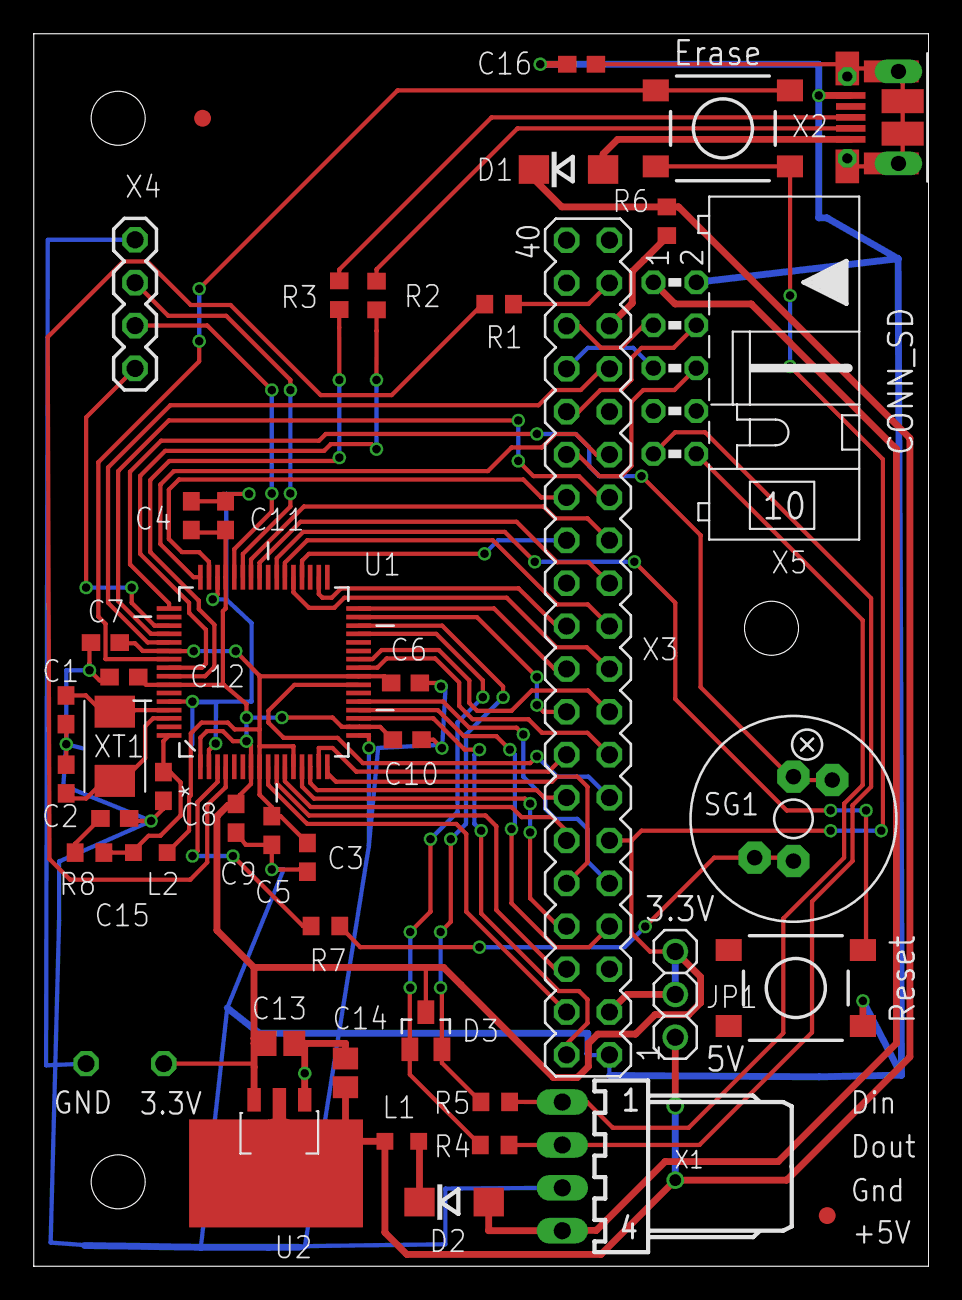
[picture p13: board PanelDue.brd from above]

Board: 2 copper layers, 53.0 x 73.0 mm, 45 parts (0 on the bottom side), 60 nets.

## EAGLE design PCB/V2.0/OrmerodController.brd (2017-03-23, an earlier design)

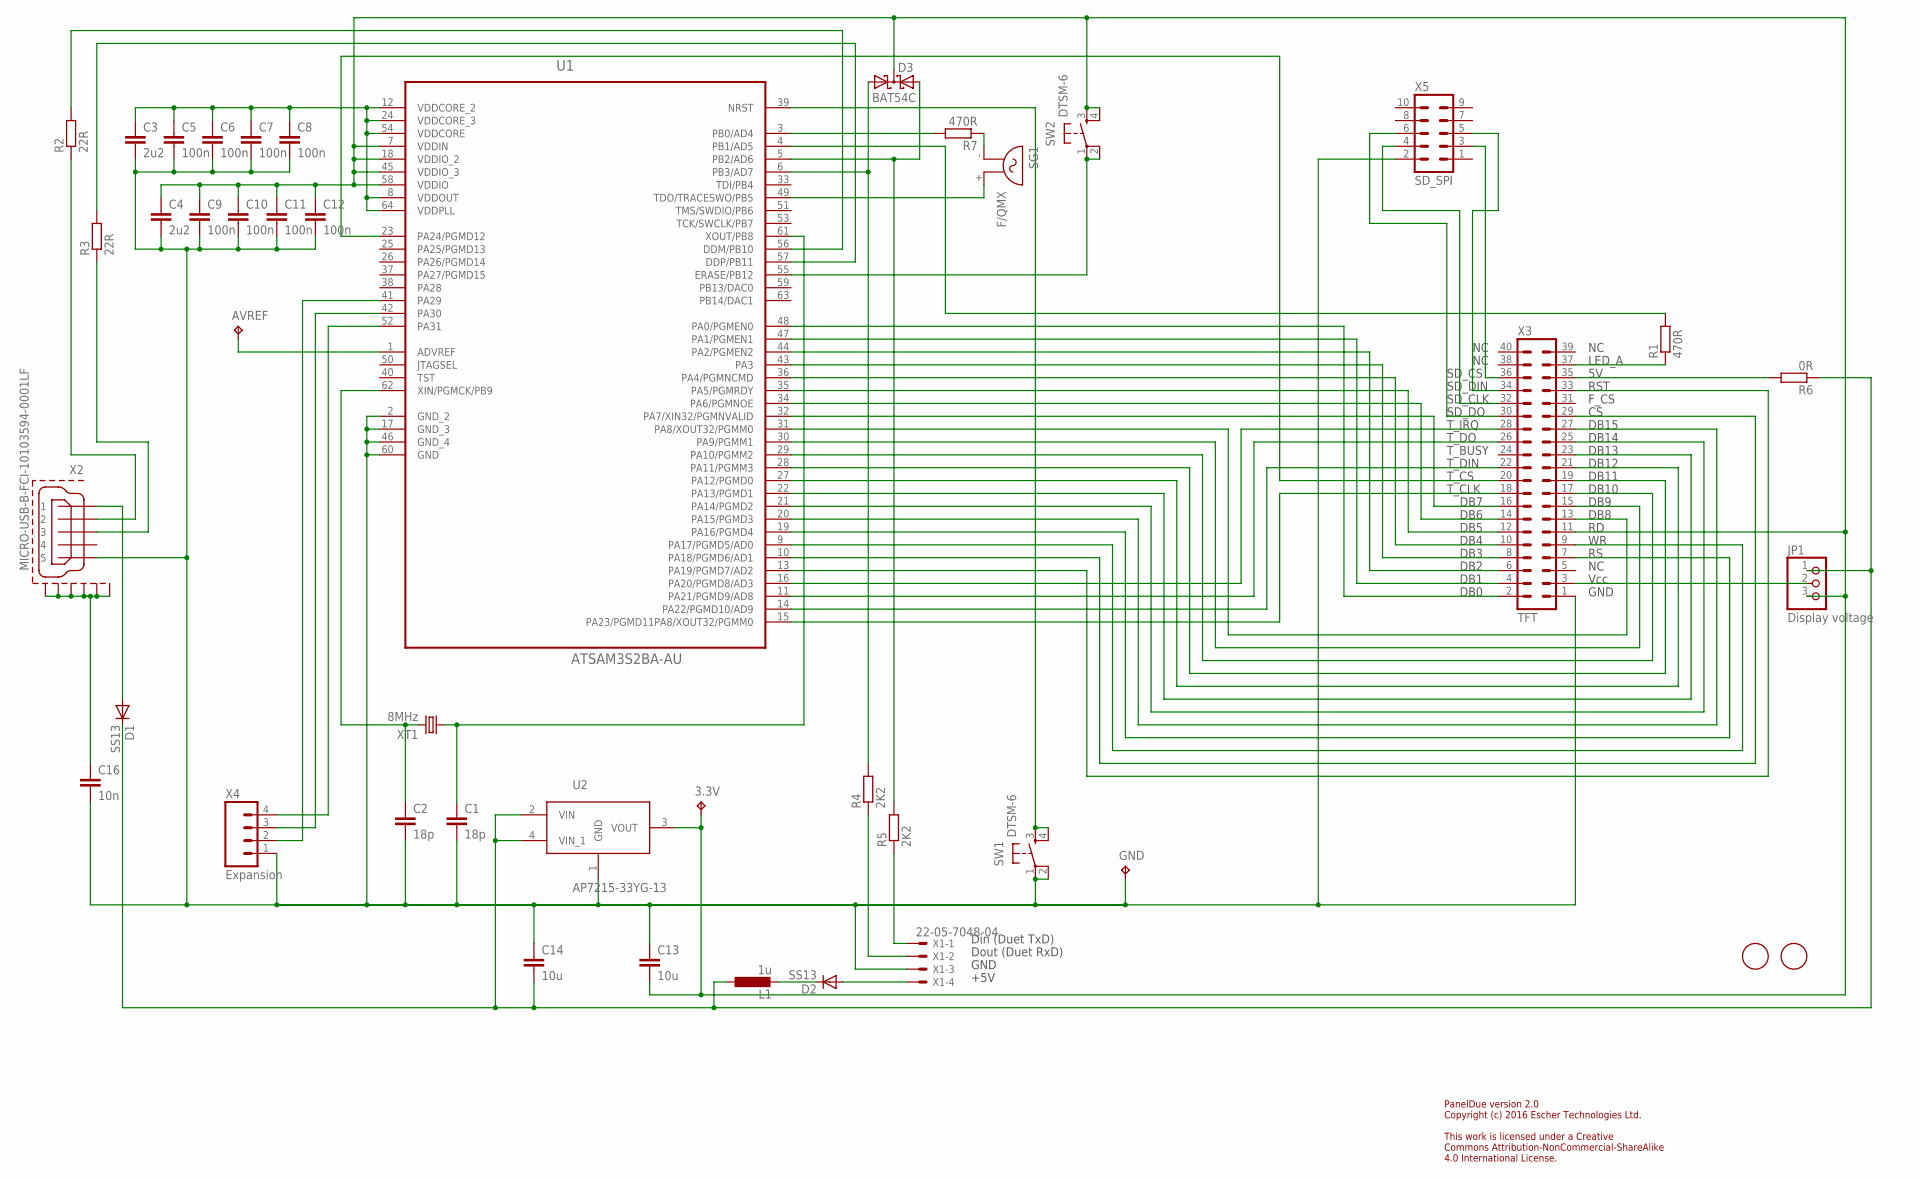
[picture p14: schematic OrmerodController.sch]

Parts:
3.3V: TPPAD1-10; P1-10
AVREF: TPPAD1-10; P1-10
C1, C2: 18p; C0603
C3, C4: 2u2; C0603
C5, C6, C7, C8, C9, C10, C11, C12: 100n; C0603
C13, C14: 10u; C0805
C16: 10n; C0603
D1, D2: SS13; DO214AC
D3: BAT54C; SOT23
GND: TPPAD1-10; P1-10
JP1: Display voltage; 1X03
L1: 1u; L2012C
R1, R7: 470R; R0603
R2, R3: 22R; R0603
R4, R5: 2K2; R0603
R6: 0R; R0603
SG1: F/QMX
SW1, SW2: DTSM-6
U1: ATSAM3S2BA-AU; QFP50P1200X1200X160-64N
U2: AP7215-33YG-13; SOT150P400X160-4N
U$1, U$2: FIDUCIAL; FIDUCIAL_1MM
X1: 22-05-7048-04; 7395-04
X2: MICRO-USB-B-FCI-10103594-0001LF; 10103594-0001LF
X3: TFT; MA20-2
X4: Expansion; 1X04
X5: SD_SPI; ML10L
XT1: 8MHz; HC49UP

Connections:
GND: C1.2, C2.2, C3.2, C4.2, C5.2, C6.2, C7.2, C8.2, C9.2, C10.2, C11.2, C12.2, C13.1, C14.1, C16.2, GND.TP, SW1.1, SW1.2, U1.2 (GND_2), U1.17 (GND_3), U1.46 (GND_4), U1.60 (GND), U2.1 (GND), X1.3, X2.5, X3.1, X4.1, X5.2
unnamed: U1.48 (PA0/PGMEN0), X3.2
unnamed: U1.15 (PA23/PGMD11PA8/XOUT32/PGMM0), X3.18
unnamed: U1.47 (PA1/PGMEN1), X3.4
unnamed: U1.44 (PA2/PGMEN2), X3.6
unnamed: U1.36 (PA4/PGMNCMD), X3.10
unnamed: U1.34 (PA6/PGMNOE), X3.14
unnamed: U1.35 (PA5/PGMRDY), X3.12
unnamed: U1.32 (PA7/XIN32/PGMNVALID), X3.16
unnamed: U1.31 (PA8/XOUT32/PGMM0), X3.13
unnamed: U1.43 (PA3), X3.8
unnamed: U1.30 (PA9/PGMM1), X3.15
unnamed: U1.29 (PA10/PGMM2), X3.17
unnamed: U1.28 (PA11/PGMM3), X3.19
unnamed: U1.27 (PA12/PGMD0), X3.21
unnamed: U1.22 (PA13/PGMD1), X3.23
unnamed: U1.21 (PA14/PGMD2), X3.25
unnamed: U1.20 (PA15/PGMD3), X3.27
unnamed: R2.2, U1.56 (DDM/PB10)
unnamed: U1.14 (PA22/PGMD10/AD9), X3.22
unnamed: U1.11 (PA21/PGMD9/AD8), X3.26
unnamed: C1.1, U1.61 (XOUT/PB8), XT1.1
unnamed: C2.1, U1.62 (XIN/PGMCK/PB9), XT1.2
unnamed: SW2.1, SW2.2, U1.55 (ERASE/PB12)
unnamed: U1.41 (PA29), X4.2
unnamed: SW1.3, SW1.4, U1.39 (NRST)
unnamed: D3.2 (A2), R5.2, U1.5 (PB2/AD6)
unnamed: D3.1 (A1), R4.2, U1.6 (PB3/AD7)
unnamed: R3.2, U1.57 (DDP/PB11)
unnamed: R4.1, X1.2
unnamed: R5.1, X1.1
unnamed: D1.A, X2.1
unnamed: R2.1, X2.2
unnamed: R7.2, U1.3 (PB0/AD4)
unnamed: R3.1, X2.3
unnamed: U1.23 (PA24/PGMD12), X3.20
unnamed: U1.16 (PA20/PGMD8/AD3), X3.28
unnamed: JP1.2, X3.3
unnamed: R1.1, X3.37
unnamed: X3.36, X5.3
unnamed: R7.1, SG1.- (1)
unnamed: U1.42 (PA30), X4.3
unnamed: U1.52 (PA31), X4.4
unnamed: U1.13 (PA19/PGMD7/AD2), X3.33
unnamed: U1.10 (PA18/PGMD6/AD1), X3.29
unnamed: U1.9 (PA17/PGMD5/AD0), X3.9
unnamed: D2.C, L1.2
unnamed: C16.1, X2.GND1, X2.GND2, X2.GND3, X2.GND4, X2.GND5, X2.GND6
unnamed: U1.19 (PA16/PGMD4), X3.7
unnamed: AVREF.TP, U1.1 (ADVREF)
unnamed: D2.A, X1.4
unnamed: X3.34, X5.5
unnamed: R1.2, U1.4 (PB1/AD5)
unnamed: SG1.+ (2), U1.49 (TDO/TRACESWO/PB5)
unnamed: C3.1, C5.1, C6.1, C7.1, C8.1, U1.8 (VDDOUT), U1.12 (VDDCORE_2), U1.24 (VDDCORE_3), U1.54 (VDDCORE), U1.64 (VDDPLL)
unnamed: X3.32, X5.4
unnamed: X3.30, X5.6
unnamed: R6.2, X3.35
VCC: 3.3V.TP, C4.1, C9.1, C10.1, C11.1, C12.1, C13.2, D3.3 (CC), JP1.3, SW2.3, SW2.4, U1.7 (VDDIN), U1.18 (VDDIO_2), U1.45 (VDDIO_3), U1.58 (VDDIO), U2.3 (VOUT), X3.11
VCC5: C14.2, D1.C, JP1.1, L1.1, R6.1, U2.2 (VIN), U2.4 (VIN_1)

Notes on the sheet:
T_BUSY
SD_CS
SD_DIN
SD_CLK
SD_DO
T_IRQ
GND
Vcc
DB0
DB1
DB2
DB3
DB4
DB5
DB6
DB7
T_CLK
T_CS
T_DIN
T_DO
DB8
DB9
DB10
DB11
DB12
DB13
DB14
DB15
F_CS
RST
LED_A
+5V
Dout (Duet RxD)
Din (Duet TxD)
PanelDue version 2.0 Copyright (c) 2016 Escher Technologies Ltd. This work is licensed under a Creative Commons Attribution-NonCommercial-ShareAlike 4.0 International License.

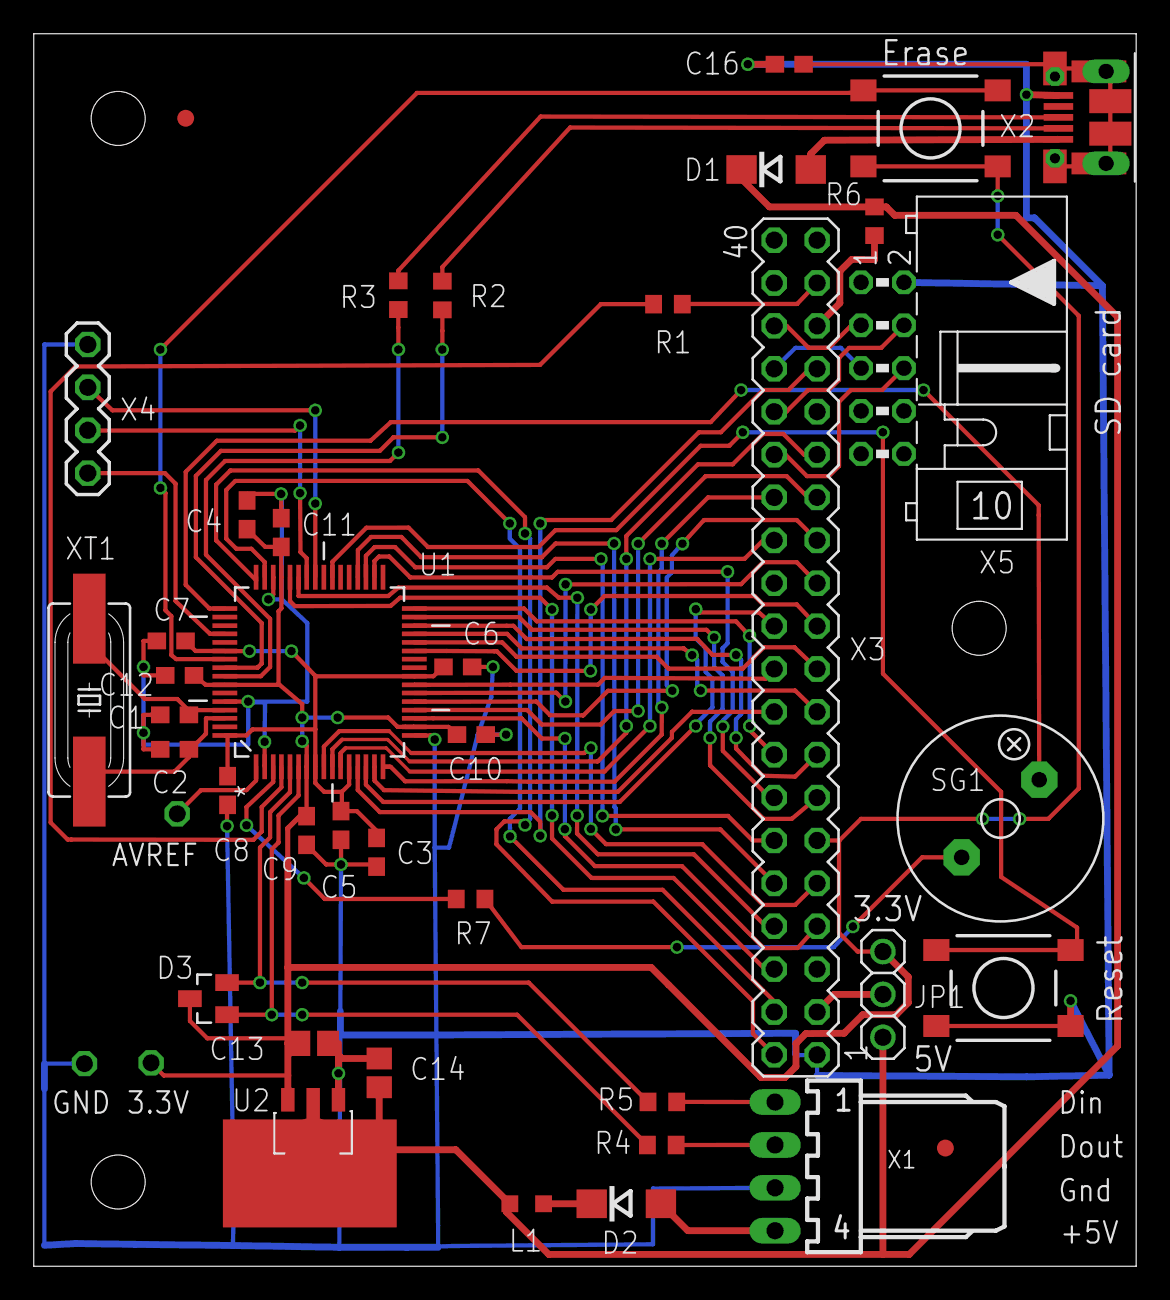
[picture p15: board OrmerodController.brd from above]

Board: 2 copper layers, 65.3 x 73.0 mm, 43 parts (0 on the bottom side), 60 nets.

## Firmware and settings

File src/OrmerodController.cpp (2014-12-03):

// Controller for Ormerod to run on SAM3S2B
// Coding rules:
//
// 1. Must compile with no g++ warnings, when all warning are enabled..
// 2. Dynamic memory allocation using 'new' is permitted during the initialization phase only. No use of 'new' anywhere else,
//    and no use of 'delete', 'malloc' or 'free' anywhere.
// 3. No pure virtual functions. This is because in release builds, having pure virtual functions causes huge amounts of the C++ library to be linked in
//    (possibly because it wants to print a message if a pure virtual function is called).

#include "asf.h"
#include "Mem.hpp"
#include "Display.hpp"
#include "UTFT.hpp"
#include "UTouch.hpp"
#include "SerialIo.hpp"
#include "Buzzer.hpp"
#include "SysTick.hpp"
#include "Misc.hpp"
#include "Vector.hpp"
#include "FlashStorage.hpp"

#define DISPLAY_TYPE_ITDB02_32WD	(0)					// Itead 3.2 inch widescreen display (400x240)
#define DISPLAY_TYPE_ITDB02_43		(1)					// Itead 4.3 inch display (480 x 272)
#define DISPLAY_TYPE_ITDB02_50		(2)					// Itead 5.0 inch display (800 x 480)

// Define DISPLAY_TYPE to be one of the above 3 types of display
//#define DISPLAY_TYPE	DISPLAY_TYPE_ITDB02_43
#define DISPLAY_TYPE	DISPLAY_TYPE_ITDB02_32WD

// From the display type, we determine the display controller type and touch screen orientation adjustment
#if DISPLAY_TYPE == DISPLAY_TYPE_ITDB02_32WD
# define DISPLAY_CONTROLLER		HX8352A
# define TOUCH_ORIENT_ADJUST	static_cast<DisplayOrientation>(SwapXY | ReverseY)
# define DISPLAY_X				(400)
# define DISPLAY_Y				(240)
#elif DISPLAY_TYPE == DISPLAY_TYPE_ITDB02_43
# define DISPLAY_CONTROLLER		SSD1963_480
# define TOUCH_ORIENT_ADJUST	Default
# define DISPLAY_X				(480)
# define DISPLAY_Y				(272)
#elif DISPLAY_TYPE == DISPLAY_TYPE_ITDB02_50
# define DISPLAY_CONTROLLER		SSD1963_800
# define TOUCH_ORIENT_ADJUST	Default
# define DISPLAY_X				(800)
# define DISPLAY_Y				(480)
#else
# error DISPLAY_TYPE is not defined correctly
#endif

// Define the row and column positions. Leave a gap of at least 1 pixel from the edges of the screen, so that we can highlight
// a field by drawing an outline.

#if DISPLAY_X == 400

const PixelNumber margin = 1;
const PixelNumber outlinePixels = 1;
const PixelNumber fieldSpacing = 4;

const PixelNumber column1 = margin;
const PixelNumber column2 = 72;
const PixelNumber column3 = 146;
const PixelNumber column4 = 208;
const PixelNumber column5 = 270;

const PixelNumber columnX = 275;
const PixelNumber columnY = 333;

const PixelNumber columnEnd = DISPLAY_X;

const PixelNumber rowCommon1 = margin;
const PixelNumber rowHeight = 22;

const PixelNumber rowTabs = DISPLAY_Y - 22 - margin;	// place at bottom of screen with a 1-pixel margin

#elif DISPLAY_X == 480

const PixelNumber margin = 2;
const PixelNumber outlinePixels = 2;
const PixelNumber fieldSpacing = 5;

const PixelNumber column1 = margin;
const PixelNumber column2 = 83;
const PixelNumber column3 = 167;
const PixelNumber column4 = 230;
const PixelNumber column5 = 311;

const PixelNumber columnX = 326;
const PixelNumber columnY = 400;

const PixelNumber columnEnd = DISPLAY_X;

const PixelNumber rowCommon1 = margin;
const PixelNumber rowHeight = 24;

const PixelNumber rowTabs = DISPLAY_Y - 22 - margin;	// place at bottom of screen with a 2-pixel margin

#endif

const PixelNumber rowCommon2 = rowCommon1 + rowHeight;
const PixelNumber rowCommon3 = rowCommon2 + rowHeight;
const PixelNumber rowCommon4 = rowCommon3 + rowHeight;
const PixelNumber rowCommon5 = rowCommon4 + rowHeight;
const PixelNumber rowCustom1 = rowCommon5 + rowHeight;
const PixelNumber rowCustom2 = rowCustom1 + rowHeight;
const PixelNumber rowCustom3 = rowCustom2 + rowHeight;
const PixelNumber rowCustom4 = rowCustom3 + rowHeight;

const PixelNumber columnTabWidth = (DISPLAY_X - 2*margin - 4*fieldSpacing)/5;

const PixelNumber columnTab1 = margin;
const PixelNumber columnTab2 = columnTab1 + columnTabWidth + fieldSpacing;
const PixelNumber columnTab3 = columnTab2 + columnTabWidth + fieldSpacing;
const PixelNumber columnTab4 = columnTab3 + columnTabWidth + fieldSpacing;
const PixelNumber columnTab5 = columnTab4 + columnTabWidth + fieldSpacing;

const PixelNumber xyPopupX = 3, xyPopupY = 195;
const PixelNumber filePopupWidth = DISPLAY_X - 40, filePopupHeight = 8 * rowHeight + 20;

const uint32_t numFileColumns = 2;
const uint32_t numFileRows = (DISPLAY_Y - margin)/rowHeight - 2;
const uint32_t numDisplayedFiles = numFileColumns * numFileRows;

// Declare which fonts we will be using
//extern uint8_t glcd16x16[];
extern uint8_t glcd19x20[];

#define DEGREE_SYMBOL	"\x81"

UTFT lcd(DISPLAY_CONTROLLER, TMode16bit, 16, 17, 18, 19);

UTouch touch(23, 24, 22, 21, 20);
DisplayManager mgr;

const uint32_t printerPollInterval = 2000;			// poll interval in milliseconds
const uint32_t printerPollTimeout = 5000;			// poll timeout in milliseconds
const uint32_t touchBeepLength = 20;				// beep length in ms
const uint32_t touchBeepFrequency = 4500;			// beep frequency in Hz. Resonant frequency of the piezo sounder is 4.5kHz.
const uint32_t longTouchDelay = 200;				// how long we ignore new touches for after pressing Set
const uint32_t shortTouchDelay = 50;				// how long we ignore new touches while pressing up/down, to get a reasonable repeat rate

static uint32_t lastTouchTime;
static uint32_t ignoreTouchTime;
static uint32_t lastResponseTime;
static uint32_t fileScrollOffset;
static bool fileListChanged = true;
static bool gotMachineName = false;
static bool axisHomed[3] = {false, false, false};
static bool allAxesHomed = false;
static int beepFrequency = 0, beepLength = 0;

String<15> machineName;
String<40> printingFile;
String<10> zprobeBuf;
String<30> generatedByText;
Vector<char, 2048> fileList;						// we use a Vector instead of a String because we store multiple null-terminated strings in it
Vector<const char* array, 100> fileIndex;			// pointers into the individual filenames in the list
static const char* array null currentFile = NULL;	// file whose info is displayed in the popup menu

struct FlashData
{
	uint32_t magic;
	int16_t xmin;
	int16_t xmax;
	int16_t ymin;
	int16_t ymax;
};

FlashData nvData;
const uint32_t magicVal = 0x3AB629D1;

enum PrinterStatus
{
	psUnknown = 0,
	psIdle = 1,
	psPrinting = 2,
	psStopped = 3
};

static PrinterStatus status = psUnknown;

const Color activeBackColor = red;
const Color standbyBackColor = yellow;
const Color defaultBackColor = blue;
const Color errorBackColour = magenta;
const Color selectableBackColor = black;
const Color outlineColor = green;
const Color popupBackColour = green;
const Color selectablePopupBackColour = UTFT::fromRGB(0, 128, 0);		// dark green
const Color homedBackColour = UTFT::fromRGB(0, 0, 100);					// dark blue
const Color notHomedBackColour = UTFT::fromRGB(128, 64, 9);				// orange

// Event numbers, used to say what we need to do when s field is touched
const Event evTabControl = 1,
			evTabPrint = 2,
			evTabFiles = 3,
			evTabMsg = 4,
			evTabInfo = 5,
			evSetVal = 6,
			evAdjustInt = 7,
			evAdjustFloat = 8,
			evSetInt = 9,
			evCalTouch = 10,
			evSelectHead = 11,
			evXYPos = 12,
			evZPos = 13,
			evFile = 14,
			evPrint = 15, evCancelPrint = 16,
			evSendCommand = 17;

static FloatField *bedCurrentTemp, *t1CurrentTemp, *t2CurrentTemp, *xPos, *yPos, *zPos, *fpHeightField, *fpLayerHeightField;
static IntegerField *bedActiveTemp, *t1ActiveTemp, *t2ActiveTemp, *t1StandbyTemp, *t2StandbyTemp, *spd, *e1Percent, *e2Percent;
static IntegerField *bedStandbyTemp, /* *fanRPM,*/ *freeMem, *touchX, *touchY, *fpSizeField, *fpFilamentField;
static ProgressBar *printProgressBar;
static StaticTextField *nameField, *head1State, *head2State, *bedState, *tabControl, *tabPrint, *tabFiles, *tabMsg, *tabInfo, *touchCalibInstruction;
static StaticTextField *filenameFields[numDisplayedFiles];
static StaticTextField *homeFields[3], *homeAllField;
static DisplayField *baseRoot, *commonRoot, *controlRoot, *printRoot, *filesRoot, *messageRoot, *infoRoot;
static DisplayField * null currentTab = NULL;
static DisplayField * null fieldBeingAdjusted = NULL;
static PopupField *setTempPopup, *setXYPopup, *setZPopup, *filePopup;
//static TextField *commandField;
static TextField *zProbe, *fpNameField, *fpGeneratedByField, *printingField;

//char commandBuffer[80];

const size_t numHeaters = 3;
int heaterStatus[numHeaters];

void RefreshFileList()
{
	for (size_t i = 0; i < numDisplayedFiles; ++i)
	{
		StaticTextField *f = filenameFields[i];
		if (i < fileIndex.size())
		{
			f->SetValue(fileIndex[i]);
			f->SetColours(white, selectableBackColor);
			f->SetEvent(evFile, i);
		}
		else
		{
			f->SetValue("");
			f->SetColours(white, defaultBackColor);
			f->SetEvent(nullEvent, i);
		}
	}
}

void changeTab(DisplayField *newTab)
{
	if (newTab != currentTab)
	{
		if (currentTab != NULL)
		{
			currentTab->SetColours(white, black);
		}
		newTab->SetColours(red, black);
		currentTab = newTab;
//		lcd.setColor(defaultBackColor);
//		lcd.fillRect(0, rowCustom1, lcd.getDisplayXSize() - 1, lcd.getDisplayYSize() - 1);
		switch(newTab->GetEvent())
		{
		case evTabControl:
			mgr.SetRoot(controlRoot);
			break;
		case evTabPrint:
			mgr.SetRoot(printRoot);
			break;
		case evTabFiles:
			SerialIo::SendString("M20 S2\n");		// ask for the list of files
			mgr.SetRoot(filesRoot);
			fileScrollOffset = 0;					// scroll to top of file list
			break;
		case evTabMsg:
			mgr.SetRoot(messageRoot);
			break;
		case evTabInfo:
			mgr.SetRoot(infoRoot);
			break;
		default:
			mgr.SetRoot(commonRoot);
			break;
		}
		mgr.ClearAll();
	}
	mgr.RefreshAll(true);
}

void InitLcd()
{
	// Setup the LCD
	lcd.InitLCD(Landscape);
	mgr.Init(defaultBackColor);
	DisplayField::SetDefaultFont(glcd19x20);
	
	// Create the fields that are always displayed
	DisplayField::SetDefaultColours(white, selectableBackColor);
	mgr.AddField(tabControl = new StaticTextField(rowTabs, columnTab1, columnTabWidth, Centre, "Control"));
	tabControl->SetEvent(evTabControl, 0);
	mgr.AddField(tabPrint = new StaticTextField(rowTabs, columnTab2, columnTabWidth, Centre, "Print"));
	tabPrint->SetEvent(evTabPrint, 0);
	mgr.AddField(tabFiles = new StaticTextField(rowTabs, columnTab3, columnTabWidth, Centre, "Files"));
	tabFiles->SetEvent(evTabFiles, 0);
	mgr.AddField(tabMsg = new StaticTextField(rowTabs, columnTab4, columnTabWidth, Centre, "Msg"));
	tabMsg->SetEvent(evTabMsg, 0);
	mgr.AddField(tabInfo = new StaticTextField(rowTabs, columnTab5, columnTabWidth, Centre, "Info"));
	tabInfo->SetEvent(evTabInfo, 0);
	
	baseRoot = mgr.GetRoot();		// save the root of fields that we usually display
	
	DisplayField::SetDefaultColours(white, red);
	
	mgr.AddField(nameField = new StaticTextField(rowCommon1, 0, lcd.getDisplayXSize(), Centre, machineName.c_str()));
	DisplayField::SetDefaultColours(white, defaultBackColor);
	
	mgr.AddField(new StaticTextField(rowCommon2, column2, column3 - column2 - fieldSpacing, Left, "Current"));
	mgr.AddField(new StaticTextField(rowCommon2, column3, column4 - column3 - fieldSpacing, Left, "Active"));
	mgr.AddField(new StaticTextField(rowCommon2, column4, column5 - column4 - fieldSpacing, Left, "St'by"));

	DisplayField::SetDefaultColours(white, selectableBackColor);
	mgr.AddField(head2State = new StaticTextField(rowCommon4, column1, column2 - column1 - fieldSpacing, Left, "Head 2"));
	mgr.AddField(head1State = new StaticTextField(rowCommon3, column1, column2 - column1 - fieldSpacing, Left, "Head 1"));
	mgr.AddField(bedState = new StaticTextField(rowCommon5, column1, column2 - column1 - fieldSpacing, Left, "Bed"));
	head1State->SetEvent(evSelectHead, 1);
	head2State->SetEvent(evSelectHead, 2);
	bedState->SetEvent(evSelectHead, 0);

	mgr.AddField(t1ActiveTemp = new IntegerField(rowCommon3, column3, column4 - column3 - fieldSpacing, NULL, DEGREE_SYMBOL "C"));
	mgr.AddField(t1StandbyTemp = new IntegerField(rowCommon3, column4, column5 - column4 - fieldSpacing, NULL, DEGREE_SYMBOL "C"));
	mgr.AddField(t2ActiveTemp = new IntegerField(rowCommon4, column3, column4 - column3 - fieldSpacing, NULL, DEGREE_SYMBOL "C"));
	mgr.AddField(t2StandbyTemp = new IntegerField(rowCommon4, column4, column5 - column4 - fieldSpacing, NULL, DEGREE_SYMBOL "C"));
	mgr.AddField(bedActiveTemp = new IntegerField(rowCommon5, column3, column4 - column3 - fieldSpacing, NULL, DEGREE_SYMBOL "C"));
	t1ActiveTemp->SetEvent(evSetVal, "G10 P1 S");
	t1StandbyTemp->SetEvent(evSetVal, "G10 P1 R");
	t2ActiveTemp->SetEvent(evSetVal, "G10 P2 S");
	t2StandbyTemp->SetEvent(evSetVal, "G10 P2 R");
	bedActiveTemp->SetEvent(evSetVal, "M140 S");

	DisplayField::SetDefaultColours(white, defaultBackColor);
	mgr.AddField(t1CurrentTemp = new FloatField(rowCommon3, column2, column3 - column2 - fieldSpacing, NULL, 1, DEGREE_SYMBOL "C"));
	mgr.AddField(t2CurrentTemp = new FloatField(rowCommon4, column2, column3 - column2 - fieldSpacing, NULL, 1, DEGREE_SYMBOL "C"));

	mgr.AddField(bedCurrentTemp = new FloatField(rowCommon5, column2, column3 - column2 - fieldSpacing, NULL, 1, DEGREE_SYMBOL "C"));
	mgr.AddField(bedStandbyTemp = new IntegerField(rowCommon5, column4, column5 - column4 - fieldSpacing, NULL, DEGREE_SYMBOL "C"));

	mgr.AddField(new StaticTextField(rowCommon2, columnX, columnY - columnX - fieldSpacing, Left, "X"));
	mgr.AddField(new StaticTextField(rowCommon2, columnY, columnEnd - columnY - fieldSpacing, Left, "Y"));
	mgr.AddField(new StaticTextField(rowCommon4, columnX, columnY - columnX - fieldSpacing, Left, "Z"));
	mgr.AddField(new StaticTextField(rowCommon4, columnY, columnEnd - columnY - fieldSpacing, Left, "Probe"));

	DisplayField::SetDefaultColours(white, selectableBackColor);
	mgr.AddField(xPos = new FloatField(rowCommon3, columnX, columnY - columnX - fieldSpacing, NULL, 1));
	mgr.AddField(yPos = new FloatField(rowCommon3, columnY, columnEnd - columnY - fieldSpacing, NULL, 1));
	mgr.AddField(zPos = new FloatField(rowCommon5, columnX, columnY - columnX - fieldSpacing, NULL, 2));
	xPos->SetEvent(evXYPos, "G1 X");
	yPos->SetEvent(evXYPos, "G1 Y");
	zPos->SetEvent(evZPos, "G1 Z");

	zprobeBuf[0] = 0;
	DisplayField::SetDefaultColours(white, defaultBackColor);
	mgr.AddField(zProbe = new TextField(rowCommon5, columnY, columnEnd - columnY - fieldSpacing, NULL, zprobeBuf.c_str()));
	
	commonRoot = mgr.GetRoot();		// save the root of fields that we usually display
	
	// Create the fields for the Control tab
	DisplayField::SetDefaultColours(white, notHomedBackColour);
	homeFields[0] = new StaticTextField(rowCustom1, column1, 90, Centre, "Home X");
	homeFields[0]->SetEvent(evSendCommand, "G28 X0");
	mgr.AddField(homeFields[0]);
	homeFields[1] = new StaticTextField(rowCustom1, column1+100, 90, Centre, "Home Y");
	homeFields[1]->SetEvent(evSendCommand, "G28 Y0");
	mgr.AddField(homeFields[1]);
	homeFields[2] = new StaticTextField(rowCustom1, column1+200, 90, Centre, "Home Z");
	homeFields[2]->SetEvent(evSendCommand, "G28 Z0");
	mgr.AddField(homeFields[2]);
	homeAllField = new StaticTextField(rowCustom1, column1+300, 90, Centre, "Home all");
	homeAllField->SetEvent(evSendCommand, "G28");
	mgr.AddField(homeAllField);
	
	controlRoot = mgr.GetRoot();

	// Create the fields for the Printing tab
	mgr.SetRoot(commonRoot);
	DisplayField::SetDefaultColours(white, defaultBackColor);
	printingFile.copyFrom("(unknown)");
	mgr.AddField(printingField = new TextField(rowCustom1, 0, DISPLAY_X, "Printing ", printingFile.c_str()));
	
	DisplayField::SetDefaultColours(white, UTFT::fromRGB(0, 160, 0));
	mgr.AddField(printProgressBar = new ProgressBar(rowCustom2, margin, 8, DISPLAY_X - 2*margin));
	mgr.Show(printProgressBar, false);

	DisplayField::SetDefaultColours(white, defaultBackColor);
	mgr.AddField(new StaticTextField(rowCustom3, 0, 70, Left, "Speed"));
	DisplayField::SetDefaultColours(white, selectableBackColor);
	mgr.AddField(spd = new IntegerField(rowCustom3, 70, 60, "", "%"));
	spd->SetValue(100);
	spd->SetEvent(evSetVal, "M220 S");
	DisplayField::SetDefaultColours(white, defaultBackColor);
	mgr.AddField(new StaticTextField(rowCustom3, 140, 30, Left, "E1"));
	DisplayField::SetDefaultColours(white, selectableBackColor);
	mgr.AddField(e1Percent = new IntegerField(rowCustom3, 170, 60, "", "%"));
	e1Percent->SetValue(100);
	e1Percent->SetEvent(evSetVal, "M221 D0 S");
	DisplayField::SetDefaultColours(white, defaultBackColor);
	mgr.AddField(new StaticTextField(rowCustom3, 250, 30, Left, "E2"));
	DisplayField::SetDefaultColours(white, selectableBackColor);
	mgr.AddField(e2Percent = new IntegerField(rowCustom3, 280, 60, "", "%"));
	e2Percent->SetValue(100);
	e2Percent->SetEvent(evSetVal, "M221 D1 S");
	
	printRoot = mgr.GetRoot();

	// Create the fields for the Files tab
	mgr.SetRoot(baseRoot);
	DisplayField::SetDefaultColours(white, defaultBackColor);
	mgr.AddField(new StaticTextField(rowCommon1, margin, DISPLAY_X - 2*margin, Centre, "Files on SD card"));
	{
		PixelNumber fileFieldWidth = (DISPLAY_X + fieldSpacing - 2*margin)/numFileColumns;
		unsigned int fileNum = 0;
		for (unsigned int r = 0; r < numFileRows; ++r)
		{
			for (unsigned int c = 0; c < numFileColumns; ++c)
			{
				StaticTextField *t = new StaticTextField(((r + 1) * rowHeight) + 1, (fileFieldWidth * c) + margin, fileFieldWidth - fieldSpacing, Left, "");
				mgr.AddField(t);
				filenameFields[fileNum] = t;
				++fileNum;
			}
		}
	}
	filesRoot = mgr.GetRoot();

	// Create the fields for the Message tab
	mgr.SetRoot(commonRoot);
	DisplayField::SetDefaultColours(white, defaultBackColor);
	messageRoot = mgr.GetRoot();

	// Create the fields for the Info tab
	mgr.SetRoot(commonRoot);
	DisplayField::SetDefaultColours(white, defaultBackColor);
	mgr.AddField(freeMem = new IntegerField(rowCustom1, margin, 195, "Free RAM: "));
	mgr.AddField(touchX = new IntegerField(rowCustom1, 200, 130, "Touch: ", ","));
	mgr.AddField(touchY = new IntegerField(rowCustom1, 330, 50, ""));
	DisplayField::SetDefaultColours(white, selectableBackColor);
	DisplayField *touchCal = new StaticTextField(rowCustom3, DISPLAY_X/2 - 75, 150, Centre, "Calibrate touch");
	touchCal->SetEvent(evCalTouch, 0);
	mgr.AddField(touchCal);

	DisplayField::SetDefaultColours(white, defaultBackColor);
	infoRoot = mgr.GetRoot();
	
	mgr.SetRoot(commonRoot);
	
	touchCalibInstruction = new StaticTextField(DISPLAY_Y/2 - 10, 0, DISPLAY_X, Centre, "Touch the spot");

	// Create the popup window used to adjust temperatures
	setTempPopup = new PopupField(130, 80, popupBackColour);
	DisplayField::SetDefaultColours(white, selectablePopupBackColour);

	DisplayField *tp = new StaticTextField(10, 10, 60, Centre, "+");
	tp->SetEvent(evAdjustInt, 1);
	setTempPopup->AddField(tp);
	tp = new StaticTextField(55, 10, 60, Centre, "Set");
	tp->SetEvent(evSetInt, 0);
	setTempPopup->AddField(tp);
	tp = new StaticTextField(100, 10, 60, Centre, "-");
	tp->SetEvent(evAdjustInt, -1);
	setTempPopup->AddField(tp);
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
int main(void)
{
    SystemInit();						// set up the clock etc.	
	wdt_disable(WDT);					// disable watchdog for now
	
	matrix_set_system_io(CCFG_SYSIO_SYSIO4 | CCFG_SYSIO_SYSIO5 | CCFG_SYSIO_SYSIO6 | CCFG_SYSIO_SYSIO7);	// enable PB4-PB7 pins
	pmc_enable_periph_clk(ID_PIOA);		// enable the PIO clock
	pmc_enable_periph_clk(ID_PIOB);		// enable the PIO clock
	pmc_enable_periph_clk(ID_PWM);		// enable the PWM clock
	pmc_enable_periph_clk(ID_UART1);	// enable UART1 clock
	
	SerialIo::Init();
	Buzzer::Init();
	InitLcd();
	touch.init(lcd.getDisplayXSize(), lcd.getDisplayYSize(), TOUCH_ORIENT_ADJUST, TpMedium);
	lastTouchTime = GetTickCount();
	
	SysTick_Config(SystemCoreClock / 1000);

	// Read parameters from flash memory (currently, just the touch calibration)
	flash_init(FLASH_ACCESS_MODE_128, 6);	
	nvData.magic = 0;
	FlashStorage::read(0, &nvData, sizeof(nvData));
	if (nvData.magic == magicVal)
	{
		touch.calibrate(nvData.xmin, nvData.xmax, nvData.ymin, nvData.ymax);
	}
	
	uint32_t lastPollTime = GetTickCount() - printerPollInterval;
	lastResponseTime = GetTickCount();		// pretend we just received a response
	for (;;)
	{
		// 1. Check for input from the serial port and process it.
		SerialIo::CheckInput();
		
		// 2. If the file list has changed, refresh it.
		if (fileListChanged)
		{
			RefreshFileList();
			fileListChanged = false;
		}
		
		// 3. Check for a touch on the touch panel.
		if (touch.dataAvailable() && GetTickCount() - lastTouchTime >= ignoreTouchTime)
		{
			if (touch.read())
			{
				int x = touch.getX();
				int y = touch.getY();
				touchX->SetValue(x);	//debug
				touchY->SetValue(y);	//debug
				DisplayField * null f = mgr.FindEvent(x, y);
				if (f != NULL)
				{
					TouchBeep();		// give audible feedback of the touch
					ProcessTouch(f);
				}
				else
				{
					f = mgr.FindEventOutsidePopup(x, y);
					if (f != NULL && f == fieldBeingAdjusted)
					{
						TouchBeep();
						ProcessTouchOutsidePopup();					
					}
				}
			}
		}
		
		// 4. Refresh the display
		updateDebugInfo();
		mgr.RefreshAll(false);
		
		// 5. Generate a beep if asked to
		if (beepFrequency != 0 && beepLength != 0)
		{
			if (beepFrequency >= 100 && beepFrequency <= 10000 && beepLength > 0)
			{
				Buzzer::Beep(beepFrequency, beepLength);
			}
			beepFrequency = beepLength = 0;
		}

		// 6. If it is time, poll the printer status.
		// When the printer is executing a homing move or other file macro, it may stop responding to polling requests.
		// Under these conditions, we slow down the rate of polling to avoid building up a large queue of them.
		uint32_t now = GetTickCount();
		if (   now - lastPollTime >= printerPollInterval			// if we haven't polled the printer too recently...
			&& (   now - lastPollTime > now - lastResponseTime		// ...and either we've had a response since the last poll...
				|| now - lastPollTime >= printerPollTimeout			// ...or we're giving up on getting a response to the last poll
			   )
		   )
		{
			lastPollTime += printerPollInterval;
			SerialIo::SendString((gotMachineName) ? "M105 S2\n" : "M105 S3\n");
		}
	}
}

// End

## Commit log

2014-11-08 Started adding UART support
2014-11-14 Added touch calibration
    Added touch calibration function. Not saved to flash memory yet.
2014-11-14 Various fixes and improvements
    [OrmerodController.cpp]
2014-11-24 Added ability to move the print head
2014-11-25 Added file list and file print
2014-12-18 Fixed problem with touch driver
    Fixed a problem whereby the touch driver sometimes reported inaccurate
    positions
2015-01-24 Added enclosure
    Added enclosure files (thanks appjaws1 and dmould). LCD cutouts and
    mounting points should be correct for the low-cost 4.3 inch display, but
    the controller PCB mounting positions, reset and erase button holes, and
    USB connector hole still need sorting out.
    [appjaws-LCD-box-with-mount-v2.scad, appjaws-LCD-mount-v1.scad, appjaws-LCD-mount-v1.stl]
2015-01-27 Version 1.01
    Temperatures, speeds and extrusion factors can now be adjusted in steps
    of 1 and
    Adjusted temperatures start art zero if they are initially negative
    Fixed touch accuracy error
    File list is now sorted and scrollable
    Added factory reset button
    Fixed problem with print status bar appearing when no print is in
    progress and extrusion factor is adjusted
2015-01-28 Finished basic design, support 3 display types
    Now has correct PCB dimensions and supports 3 types of display
    [LCD-box-alt-4.3.stl, LCD-box-itead-4.3.stl, LCD-box-itead-5.0.stl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]
2015-01-29 Corrected design and renamed files
    [LCD-box-alt-4.3.stl, LCD-box-itead-5.0.stl, PanelDueEnclosure-Itead-4.3.stl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]
2015-02-07 Version 1.03
    Corrected typo in quick commands
    SD card files can now be deleted
    Added "Are you sure?" dialog
    Beep volume can be adjusted
    Separate button to save settings
    Show baud rate on Settings screen
    [Fields.hpp]
2015-02-21 Version 1.04
    Added message log
    Added print pause/resume/cancel buttons
    Added print time estimates
2015-02-24 Version 1.05
    Fixed issue with not being able to set beep volume
    Improved display of print time remaining
    Fetch filename if a print is started from another source, or already in
    progress when PanelDue is reset
2015-02-27 Version 1.06
    Implemented macros
    Minor layout changes
    Switch to printing page if PanelDue is started when the printer is
    printing or paused
2015-03-04 Version 1.07
    Added support for UTF8 code points 0xA0 to 0xFF, by generating new fonts
    and translating fro UTF8 in display driver
    Support 5 inch screen properly by adding 28x32 font and adjusting field
    Bug fix: after re-running touch calibration, the user was not warned
    that settings were not saved
    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
    [Fields.hpp]
2015-03-24 Version 1.08
    Tool numbers are now assumed to be T0 and T1 instead of T1 and T2
    Improved spacing of macro buttons on 5 inch display
    Increased max length of "Generated by" text for 5 inch display
2015-04-09 Updated enclosure model
    Changed to enclosure model:
    - Wall thickness increased to 2.4mm for compatibility with slic3r
    default extrusion width on 0.5mm Ormerod
    - Pillar diameter increased to improve strength
    - Holes for self tapping screws increased to 2.2mm
    - Guide tubes added for Reset and Erase buttons
    [PanelDueEnclosure-Itead-4.3.stl, PanelDueEnclosure-Itead-5.0.stl, PanelDueEnclosure-alt-4.3.stl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]
2015-07-26 Added production PCB files
    [OrmerodController.brd, OrmerodController.sch]
2015-08-30 Version 1.10
    Changed appearance to be slightly less antique
    Fixed file delete problem
    Bed comp or auto cal button now displayed with the homing buttons
    [PanelDueEnclosureWithLip-alt-4.3.stl, PanelDueEnclosureWithLip.scad]
2015-10-23 Added option for alternative 5 inch display
    [PanelDueEnclosureWithLip-alt-5.0.stl, PanelDueEnclosureWithLip.scad]
2015-10-24 Interim version
    Added support for icon buttons
    Refactored DisplayField and Button classes
    Moved fonts to separate folder
    Converted to Atmel Studio 7
2015-10-31 Corrected visible area for alt 5 inch display
    [PanelDueEnclosureWithLip.scad]
2015-10-31 Updated STL for alt 5 inch display
    [PanelDueEnclosureWithLip-alt-5.0.stl]
2015-11-08 Version 1.12 beta 1
    Changed some buttons to have icons instead of text.
    Support up to 4 hot ends on the 4.3 and 6 hot ends on the 5 inch
    display.
    Gcode file list is now a popup,. Uses the same one for macros.
    Added keyboard for entering gcodes.
    Added language configuration.
2015-11-18 Version 1.12
    Improved touch behaviour, in particular for 7" display
    Allow fan speed setting to be cancelled
2015-11-30 Added 7" display and increased USB cutout size
    Added dimension for the 7 inch display
    Increase size of USB cutout to take a USB plug
    Increase hole sizes for PCB and LCD mounts
    [PanelDueEnclosureWithLip-7.0.stl, PanelDueEnclosureWithLip.scad]
2015-12-06 Version 1.13
    Fixed issue with repeated sending of M20 command
    Improved the way that the command history works
    Improved the home icons
    Pick up the fan speed form the M408 status response, if present
    [Fields.hpp]
2016-01-23 Added 7 inch option to enclosure design
    [PanelDueEnclosure.scad, PanelDueEnclosureWithLip.scad]
2016-02-12 Minor changes to enclosure model
    [PanelDueEnclosure.scad]
2016-06-12 Version 1.14
    Implemented alert messages (M117)
    Added new state for firmware update
    Added ':' key to keyboard
    Close buttons are now always placed in the top right hand corner of the
    window
    Layer height is now displayed to 2 decimal places
    Icons are inverted correctly when the Invert Display option is used
    [PanelDueEnclosure.scad]
2016-09-05 Version 1.15 beta 2
    Added support for multiple colour schemes - not yet complete because we
    need icons with palettes to finish this
    Improved layout of file intormation popup
    Improved keyboard layout
    Clear popups when reconnected after firmware update
    Moved SD card icon to first page
    Support a second SD card when connected to hardware that support it
    (needs RRF 1.15c)
    M117 with no argument clears an existing alert
    When a print finishes, revert to displaying the machine name in the
    title bar
    Provide brightness control, where the hardware supports it
    Improve colours of current temperature field when in the fault state
    Handle new heater status 'tuning'
    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
    [PanelDueEnclosure.scad]
2016-09-08 Updated enclosures
    Updated enclosures for board version 2.0
    [PanelDueEnclosure-4.3-v1.1.stl, PanelDueEnclosure-5.0-v2-sdslot.stl, PanelDueEnclosure.scad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]
2016-10-19 Version 1.15
    Added support for U axis on 4.3 and U,V,W axes on 5 and 7 inch screens
    Allow more than 3 heaters to be displayed
    Speed up drawing of graphics
    [PanelDueEnclosure.scad, PanelDueEnclosureWithLip-7.0-v2.0.stl]
2016-10-21 Release 1.15a
    Show U,V,W axis positions if these axes are present
    Increased backlight PWM frequency to 250Hz to reduce flicker on 4.3"
    screen
2016-10-23 Version 1.15c
    Corrected touch spot colours when dark theme is used
    Presisng bed tool button now switchws the bed heater between active and
    standby
    [Fields.hpp]
2017-01-04 Updated enclosure model
    [PanelDueEnclosure.scad]
2017-03-23 Added version 2.0 files
    [OrmerodController.brd, OrmerodController.sch]
2017-06-19 Corrected schematic, removed binaries
    Corrected crystal frequency in schematic
    Removed old binaries
2017-08-27 Corrected lid in PanelDueEnclosure.scad
    [PanelDueEnclosure.scad]
2017-09-17 Added version 3 schematic and PCB
    [PanelDue.brd, PanelDue.sch]

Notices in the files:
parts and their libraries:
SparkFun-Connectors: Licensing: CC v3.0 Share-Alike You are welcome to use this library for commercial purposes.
